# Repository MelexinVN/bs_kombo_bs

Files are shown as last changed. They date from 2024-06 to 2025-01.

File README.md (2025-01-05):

# БС ("Брейн система")

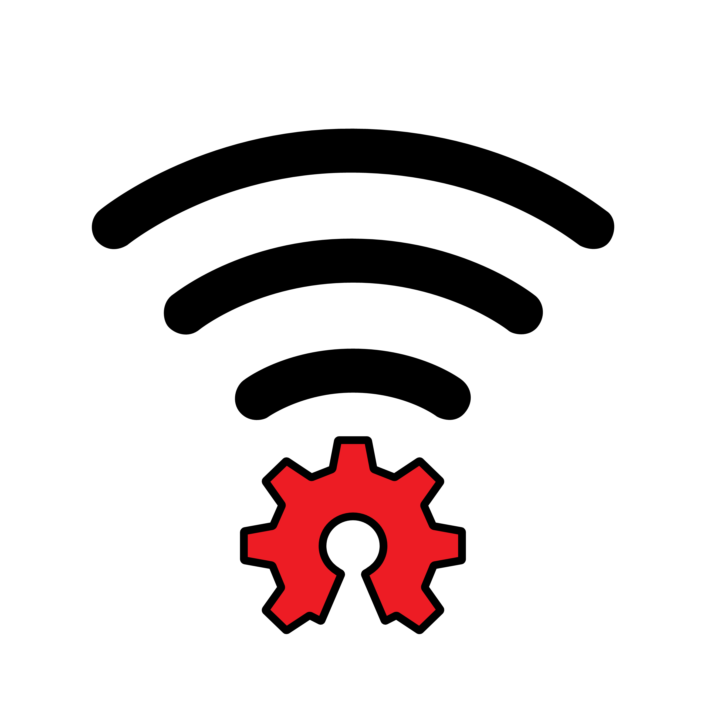
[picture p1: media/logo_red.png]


В рамках проекта ["КомБО"](https://github.com/MelexinVN/bs_kombo) разработана электронная система для проведения интеллектуальных игр.
Система без использования проводной связи позволяет устанавливать точную последовательность нажатий до 20 игровых кнопок.

As part of the project ["КомБО"](https://github.com/MelexinVN/bs_kombo), an electronic system for conducting intellectual games has been developed.
The wireless system allows you to set the exact sequence of pressing up to 20 game buttons.

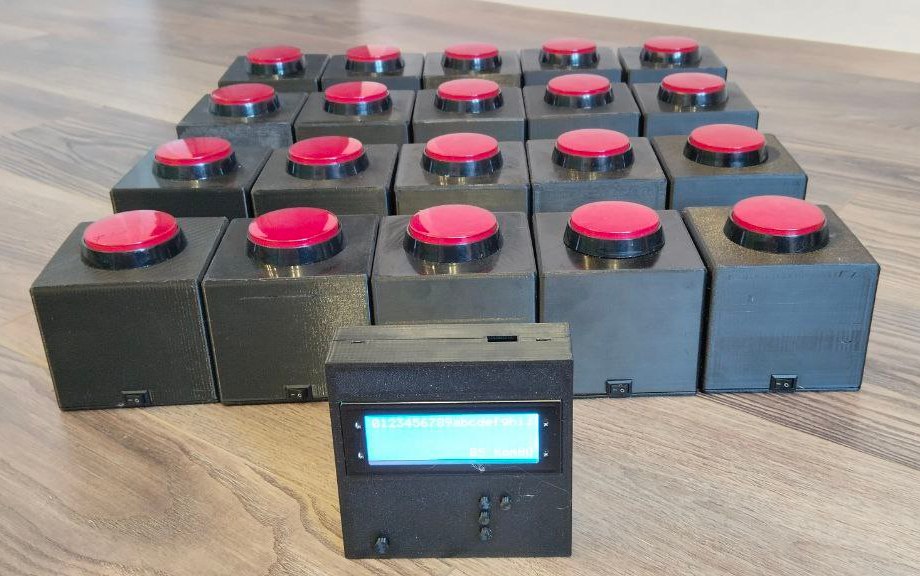
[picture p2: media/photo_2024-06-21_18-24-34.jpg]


### Основные характеристики системы

- беспроводная связь базы с игровыми кнопками
- частота радиоканала - 2,4-2,56 ГГц
- дальность связи - 30 м в помещении (может зависеть от зашумленности помещения радиосигналами, перегородок и преград)
- количество кнопок - до 20 шт
- питание каждой игровой кнопки осуществляется от аккумулятора
- питание базы может осуществляться через USB кабель, а также автономно - от аккумулятора

### Main characteristics of the system

- wireless connection of the base with game buttons
- radio channel frequency - 2.4-2.56 GHz
- communication range - 30 m indoors (may depend on the noise level of the room due to radio signals, partitions and obstacles)
- number of buttons - up to 20 pcs.
- each game button is powered by a battery
- the base can be powered via a USB cable, or autonomously - from a battery

### Основные функции системы

- отображение хода игры на дисплее и в специальной программе на ПК
- воспроизведение звуковых файлов (mp3) при различных событиях как через ПК, так и автономно
- возможность замены звуковых файлов
- отдельная индикация первой нажатой игровой кнопки
- возможность перехода очереди нажатых кнопок
- возможность запуска времени и фиксации фальстарта

### Basic system functions

- display of the game progress on the display and in a special program on the PC
- playback of sound files (mp3) for various events both via a PC and autonomously
- ability to replace sound files
- separate indication of the first pressed game button
- the ability to move through the queue of pressed buttons
- ability to start time and fix false start

### Состав системы System composition

Система состоит из базы и комплекта игровых кнопок.

The system consists of a base and a set of game buttons.

База содержит контроллер (stm32f103c8t6 на плате bluepill), дисплей LCD2004, радиомодуль nrf24l01+, кнопки управления, USB-мост CP2102, звуковой модуль DFPlayer mini и схему питания.

The base contains a controller (stm32f103c8t6 on a bluepill board), an LCD2004 display, an nrf24l01+ radio module, control buttons, a CP2102 USB bridge, a DFPlayer mini sound module and a power circuit.

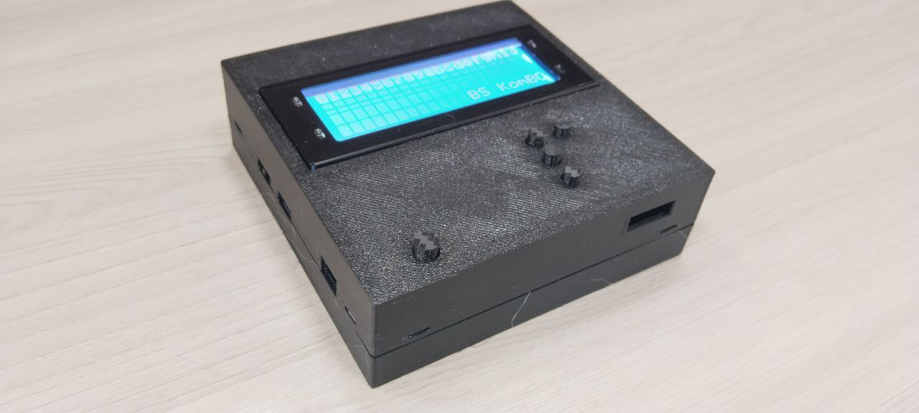
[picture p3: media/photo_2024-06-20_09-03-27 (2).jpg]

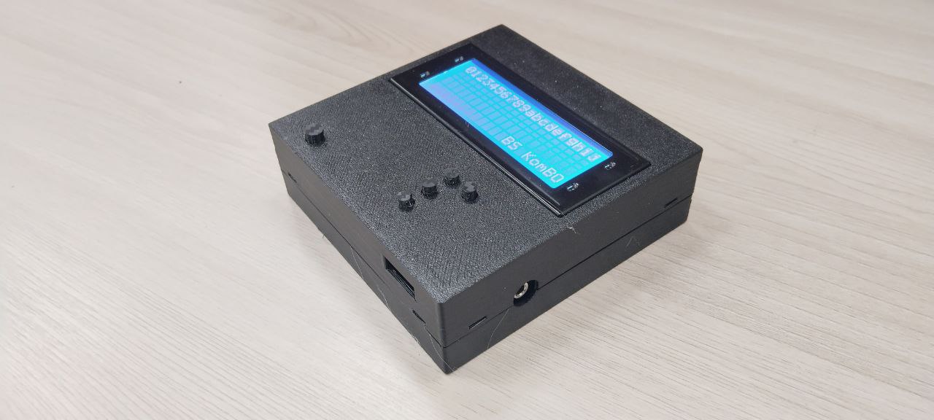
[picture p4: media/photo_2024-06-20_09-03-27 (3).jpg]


Каждая игровая кнопка содержит схему управления на микроконтроллере stm32f030f4p6 с радиомодулем nrf24l01+, схему питания и аркадную кнопку.

Each game button contains a control circuit on a stm32f030f4p6 microcontroller with an nrf24l01+ radio module, a power circuit and an arcade button.

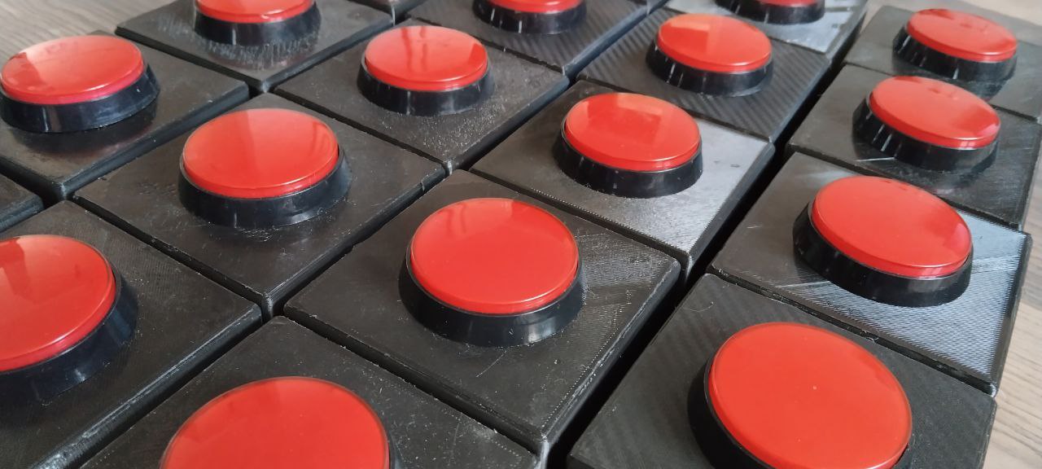
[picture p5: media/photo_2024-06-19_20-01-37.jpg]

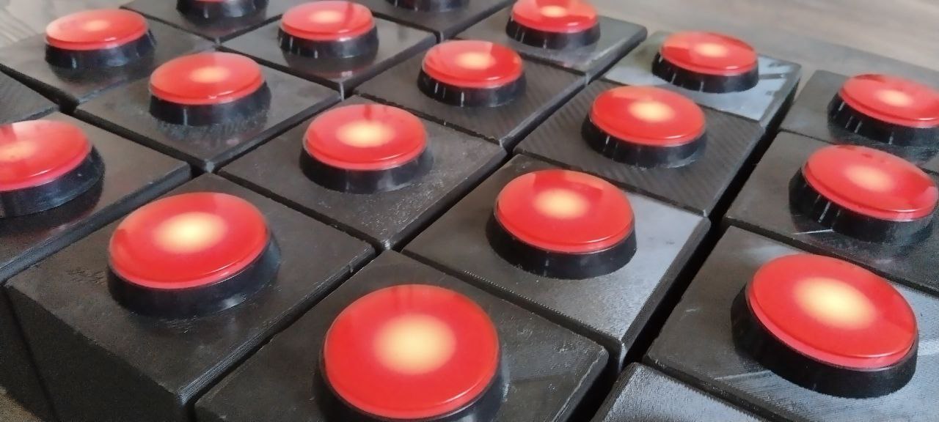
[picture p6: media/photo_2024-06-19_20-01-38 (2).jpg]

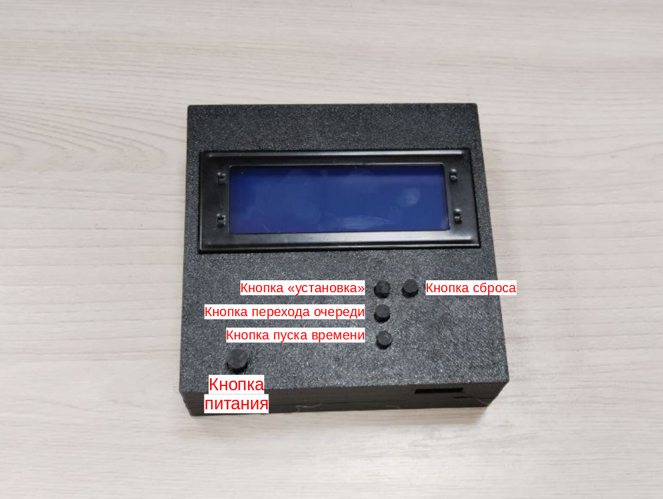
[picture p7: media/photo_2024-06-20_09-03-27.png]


### Схема соединений игровой кнопки Game Button Connection Diagram

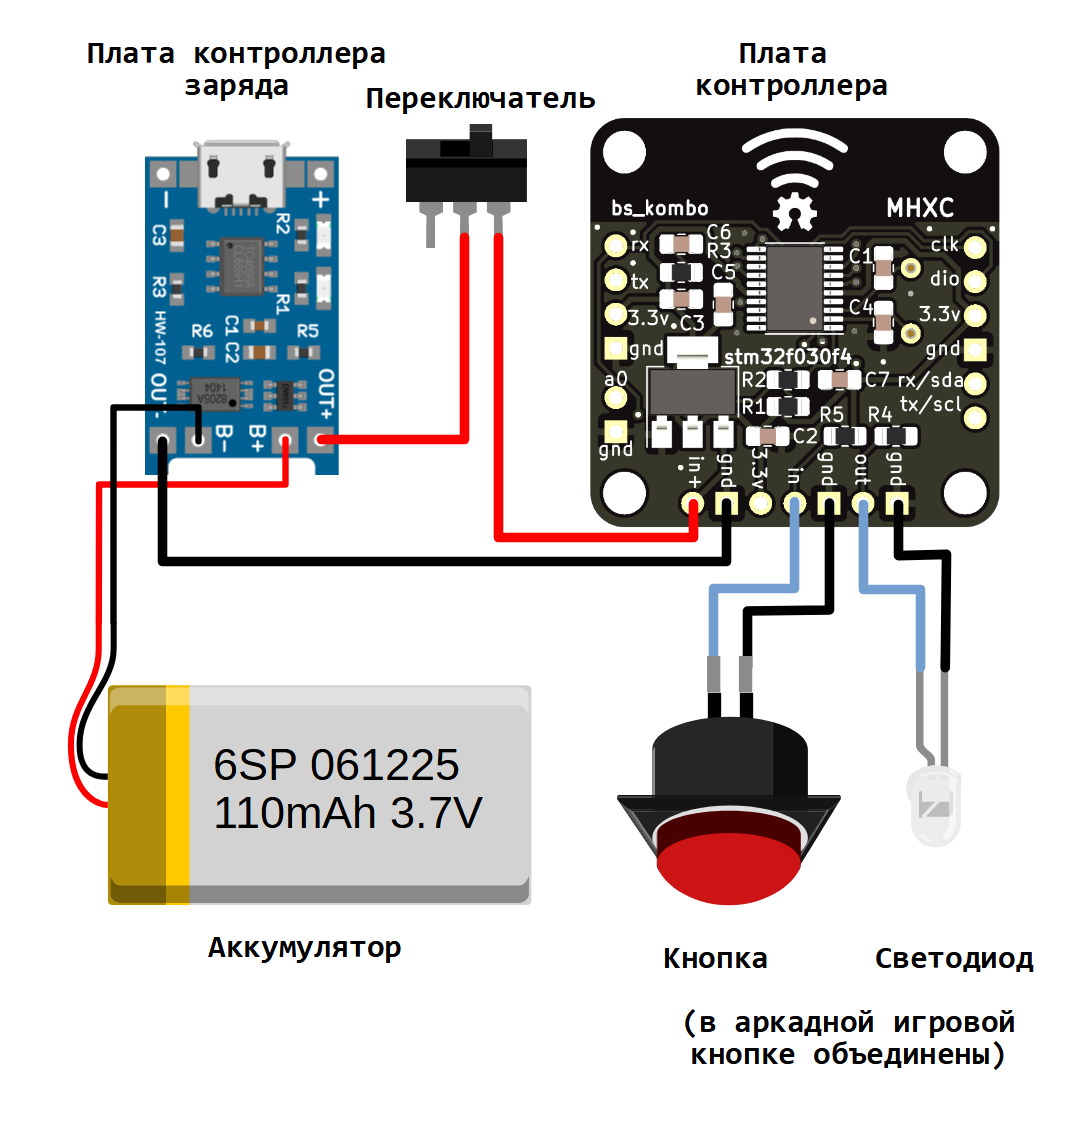
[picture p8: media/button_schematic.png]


### Программное обеспечение

- МикроПО базы и игровой кнопки написаны в Keil uVision, есть вариант в STM32CubeIDE.
- ПО для ОС Windows написано в Visual Studio.

Все [исходники](https://github.com/MelexinVN/bs_kombo_bs/blob/main/soft) доступны в репозитории.

Готовые файлы прошивок доступны по следующим ссылкам - [прошивка базы](https://disk.yandex.ru/d/3vqxKnFV9-CHBA), [прошивки игровых кнопок (20 штук)](https://disk.yandex.ru/d/9PwJGGSHZjBadQ).

### Software

- The microsoftware base and buttons are written in Keil uVision, there is an option in STM32CubeIDE.
- Software for Windows OS is written in Visual Studio.

All [sources](https://github.com/MelexinVN/bs_kombo_bs/blob/main/soft) are available in the repository.

Ready-made firmware files are available at the following links - [base firmware](https://disk.yandex.ru/d/3vqxKnFV9-CHBA), [gaming button firmware (20 pieces)](https://disk.yandex.ru/d/9PwJGGSHZjBadQ).

### Печатные платы

Печатные платы разработаны в KiCad 7.0, [исходники и гребер файлы](https://github.com/MelexinVN/bs_kombo_bs/blob/main/pcb) также есть в репозитории - [плата контроллера кнопки](https://github.com/MelexinVN/bs_kombo_bs/blob/main/pcb/bs_button_v.1.0), [плата базы](https://github.com/MelexinVN/bs_kombo_bs/blob/main/pcb/bs_base_v.1.0)

### Printed circuit boards

The printed circuit boards were developed in KiCad 7.0, [source and comb files](https://github.com/MelexinVN/bs_kombo_bs/blob/main/pcb) also available in the repository - [button controller board](https://github.com/MelexinVN/bs_kombo_bs/blob/main/pcb/bs_button_v.1.0), [base board](https://github.com/MelexinVN/bs_kombo_bs/blob/main/pcb/bs_base_v.1.0)

### Корпуса

Корпуса и вспомогательные детали изготовлены при помощи 3Д печати.
Модели корпусов разработаны в программе OpenSCAD, [исходники и STL файлы](https://github.com/MelexinVN/bs_kombo_bs/blob/main/3d) доступны в репозитории - [корпус кнопки](https://github.com/MelexinVN/bs_kombo_bs/blob/main/3d/button_box_v.1.0), [корпус и детали базы](https://github.com/MelexinVN/bs_kombo_bs/blob/main/3d/base_box_v.1.0)

### Housings

The housings and auxiliary parts are made using 3D printing.
Case models were developed in the OpenSCAD program, [sources and STL files](https://github.com/MelexinVN/bs_kombo_bs/blob/main/3d) are available in the repository - [button case](https://github.com/MelexinVN/bs_kombo_bs/blob/main/3d/button_box_v.1.0), [body and base details](https://github.com/MelexinVN/bs_kombo_bs/blob/main/3d/base_box_v.1.0)

### Краткое описание работы системы

После включения питания каждой игровой кнопки, ее светодиод производит три коротких моргания (при неисправности радиомодуля - одно). После чего игровая кнопка готова к работе
*Примечание: таким образом можно оценить состояние питания игровой кнопки - при низкой яркости аккумулятор разряжен, при отсутствии морганий возможна неисправность схемы питания*

После включения питания базы на дисплей выводится информация о устройстве, версии ПО, состоянию радиомодуля, номере канала.
Через секунду база отправляет в эфир команду общего сброса. База готова к работе.

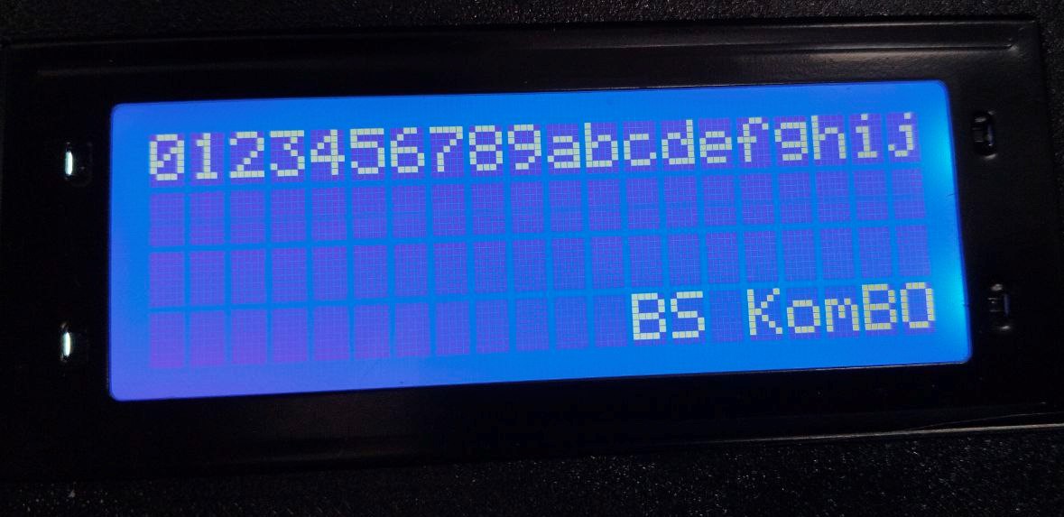
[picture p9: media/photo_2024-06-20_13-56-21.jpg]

На верхней строчке дисплея номера кнопок от "0" до "j"

По нажатию кнопки сброса система возвращается в исходное состояние и также отправляет в эфир команду общего сброса.
**Рекомендуется нажимать кнопку сброса после включения всех кнопок. Если какая то из кнопок была включена после сброса системы, возможна ошибка установления последовательности нажатий!**
Каждая игровая кнопка получившая команду сброса моргает светодиодом один раз.

После того как вся система приведена в готовность, нажатие каждой кнопки будет составлять очередь на второй строке дисплея - также от "0" до "j" и будет вопроизводиться звуковой файл. Светодиод первой нажатой игровой кнопки будет моргать, остальные - светиться.

После нажатия кнопки перехода очереди светодиод первой в очереди игровой кнопки гаснет, моргать начинает следующая в очереди.

Нажатие кнопки пуска времени приводит к началу отсчета времени - воспроизводится соответствующий звуковой сигнал, а на дисплее появляется таймер, отсчитывающий секунды. 

Нажатие кнопки установки приводит к изменению звукового файла, воспроизводимого при нажатии игровой кнопки **ДО** пуска времени. При этом на дисплее появится название звука, один из пяти вариантов.
*Примечание: выбранный звук сохранится после нажатия кнопки сброса, но вернется к стандартному при отключении питания*

Источником звуков при автономной работе является звуковой модуль, аудиовыход которого выведен на корпус в виде аудио гнезда 3,5 мм. Звуковой модуль воспроизводит звуковые файлы формата mp3, записанные на карте памяти microSD. Файлы можно заменить, но они должны иметь те же имена. Стандартное содержимое карты памяти можно найти [тут](https://disk.yandex.ru/d/iv4f7-gtp3TiZA). Файлы должны находиться в корне карты памяти.

**Предусмотрена возможность отображения хода игры и управления системой с помощью программы верхнего уровня. Описание программы и инструкцию можно найти [тут](https://github.com/MelexinVN/bs_kombo_bs/tree/main/soft/Visual%20Studio)**

### Brief description of the system operation

After turning on the power of each game button, its LED produces three short blinks (if the radio module is faulty - one). After which the game button is ready for use
*Note: this way you can evaluate the power status of the game button - if the brightness is low, the battery is discharged, if there is no blinking, the power circuit may be faulty*

After turning on the power of the base, information about the device, software version, radio module status, and channel number is displayed.
A second later, the base sends a general reset command over the air. The base is ready for use.


On the top line of the display there are button numbers from “0” to “j”

When the reset button is pressed, the system returns to its original state and also sends a general reset command over the air.
**It is recommended to press the reset button after all buttons have been turned on. If any of the buttons was turned on after resetting the system, there may be an error in establishing the sequence of presses!**
Each game button that receives a reset command blinks its LED once.

Once the entire system is ready, pressing each button will line up on the second line of the display - also from "0" to "j" - and a sound file will be played. The LED of the first pressed game button will blink, the others will light up.

After pressing the queue switch button, the LED of the first game button in the queue goes out, and the next one in the queue starts blinking.

Pressing the start time button starts the countdown - a corresponding sound signal is played, and a timer appears on the display, counting down the seconds.

Pressing the set button changes the sound file played when the game button **BEFORE** the time starts is pressed. In this case, the name of the sound will appear on the display, one of five options.
*Note: The selected sound will remain after pressing the reset button, but will return to standard when the power is turned off*

The source of sounds during autonomous operation is the sound module, the audio output of which is connected to the case in the form of a 3.5 mm audio jack. The sound module plays mp3 audio files recorded on a microSD memory card. The files can be replaced, but they must have the same names. The standard contents of the memory card can be found [here](https://disk.yandex.ru/d/iv4f7-gtp3TiZA). The files must be located in the root of the memory card.

**It is possible to display the progress of the game and control the system using a top-level program. A description of the program and instructions can be found [here](https://github.com/MelexinVN/bs_kombo_bs/tree/main/soft/Visual%20Studio)**

### Планы по развитию:
- **Переход на более компактную базу с цветным дисплеем**
- **Отображение информации о наличии кнопок в эфире**
- **Отображение информации об уровнях заряда кнопок и базы**
- **Добавление возможности перехода на другие радиоканалы в случае зашумленности помещения**
- **Более гибкая настройка программы верхнего уровня для большей информативности и для разных видов интеллектуальных игр**

### Development plans:
- **Transition to a more compact base with a color display**
- **Displaying information about the presence of buttons on air**
- **Display information about charge levels of buttons and base**
- **Adding the ability to switch to other radio channels in case of a noisy room**
- **More flexible configuration of the top-level program for greater information content and for different types of intellectual games**

## Наши ресурсы:

### Основной репозиторий: [bs_kombo](https://github.com/MelexinVN/bs_kombo)

### Электронная почта: 		    [bskombo@yandex.ru](bskombo@yandex.ru)

### Социальные сети:

- паблик ВКонтакте: 			  [vk.com/bs_kombo](https://vk.com/bs_kombo)
- Telegram-канал: 	        [t.me/bskombo](https://t.me/bskombo)
- Telegram-чат: 	          [t.me/bs_kombo_chat](https://t.me/bs_kombo_chat)

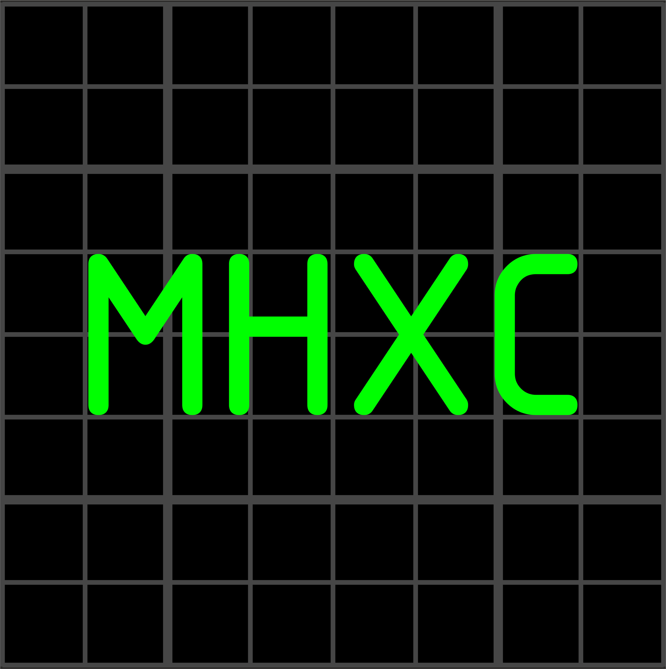
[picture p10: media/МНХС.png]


### Авторы всегда рады отзывам и любым конструктивным предложениям по улучшению проекта! 
### The authors are always happy to receive feedback and any constructive suggestions for improving the project!

## Лицензия
Проект распространяется под лицензией Creative Commons Attribution-ShareAlike 4.0 [CC BY-SA 4.0](https://creativecommons.org/licenses/by-sa/4.0/), 
а программное обеспечение - под лицензией GNU General Public License v3.0 [GPL-3.0 license](https://github.com/MelexinVN/bs_kombo/blob/main/LICENSE)

## License
This project is licensed under the Creative Commons 4.0 license with Attribution-ShareAlike [CC BY-SA 4.0](https://creativecommons.org/licenses/by-sa/4.0/), 
and the software is licensed under the GNU General Public License v3.0 [GPL-3.0 license](https://github.com/MelexinVN/bs_kombo/blob/main/LICENSE)

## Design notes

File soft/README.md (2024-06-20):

## Программное обеспечение системы.

### В папке [Keil uVision](https://github.com/MelexinVN/bs_kombo_bs/blob/main/soft/Keil%20uVision) содержатся проекты программ функционирования базы и игровых кнопок, написанные в среде Keil версии 5.38 преимущественно на языке Си

### В папке [STM32CubeIDE](https://github.com/MelexinVN/bs_kombo_bs/blob/main/soft/STM32CubeIDE) содержатся проекты программ функционирования базы и игровых кнопок, написанные в среде STM32CubeIDE v.1.15.0 преимущественно на языке Си

### В папке [Visual Studio](https://github.com/MelexinVN/bs_kombo_bs/blob/main/soft/Visual%20Studio) содержатся исходники программы верхнего уровня для ОС Windows, написанные в Visual Studio 2019 на языке C#

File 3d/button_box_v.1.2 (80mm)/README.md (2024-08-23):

## 3Д модели 3д-печатных деталей устройства.

## Корпус игровой кнопки. Версия 1.2 
- Внутренние размеры - 80x80x80 мм
- Требует меньше материала и времени на печать
- Можно печатать без поддержек и настройки "сделать нависания печатаемыми"
- Меньше радиус крепежных элементов корпуса

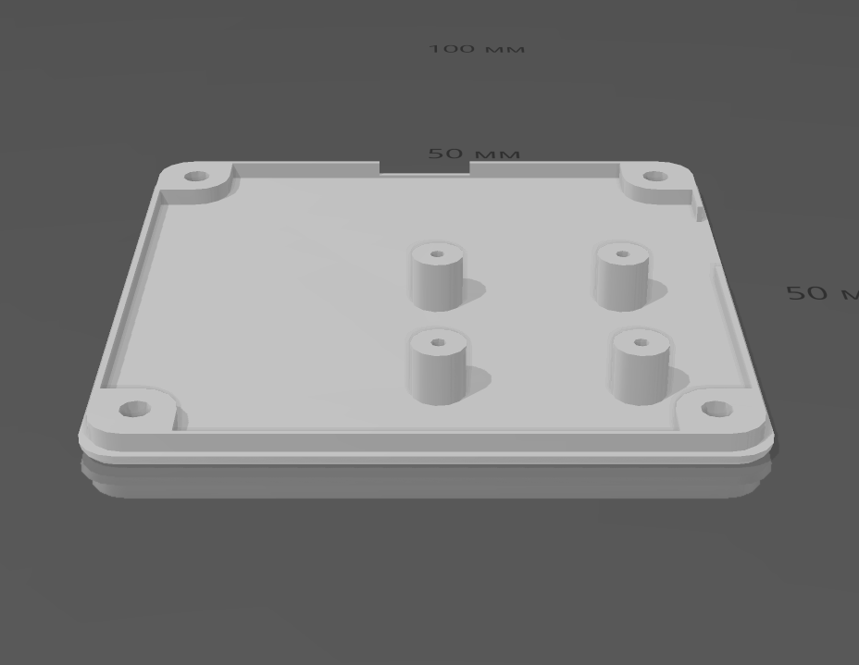
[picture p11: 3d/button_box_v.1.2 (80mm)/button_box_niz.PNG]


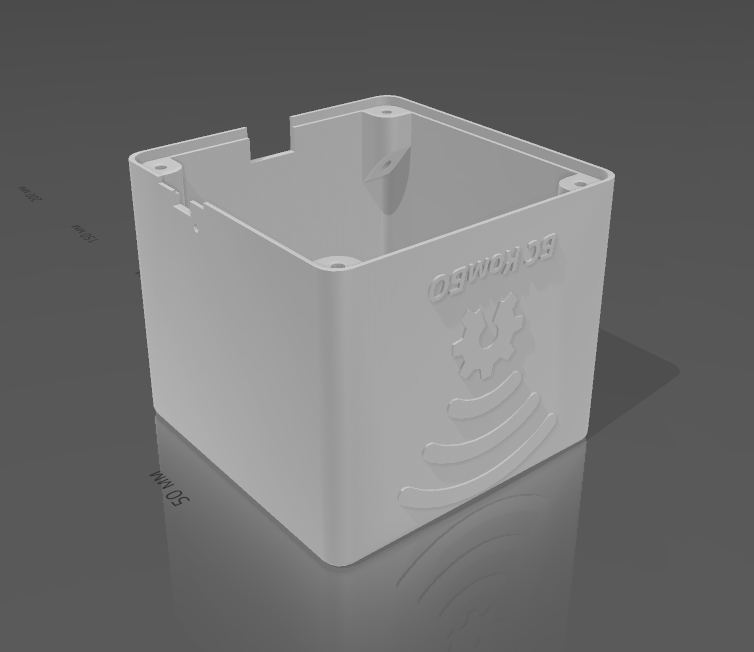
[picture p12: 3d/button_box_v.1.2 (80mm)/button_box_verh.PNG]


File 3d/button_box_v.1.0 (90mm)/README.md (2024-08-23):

## 3Д модели и исходники 3д-печатных деталей устройства.
### 3Д модели созданы в программе [OpenSCAD](https://openscad.org/)
### Корпус пульта управления создан с использованием библиотеки YAPP_Box 
### [Yet Another Parameterised Projectbox generator](https://mrwheel-docs.gitbook.io/yappgenerator_en/)
**!!! При печати нижней части корпуса кнопки без поддержек рекомендуется включить настройку "Сделать нависания печатаемыми"!!!**

## Корпус игровой кнопки
- Внутренние размеры - 90x90x90 мм

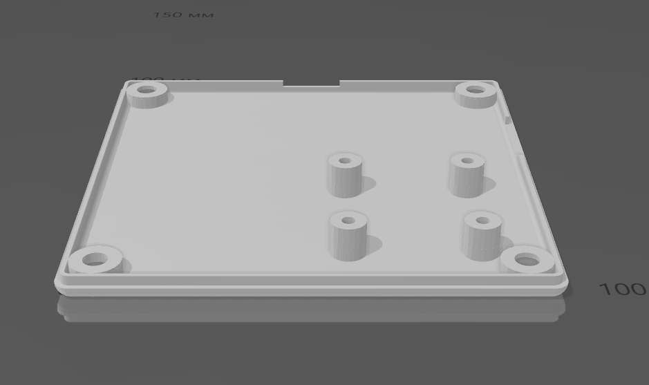
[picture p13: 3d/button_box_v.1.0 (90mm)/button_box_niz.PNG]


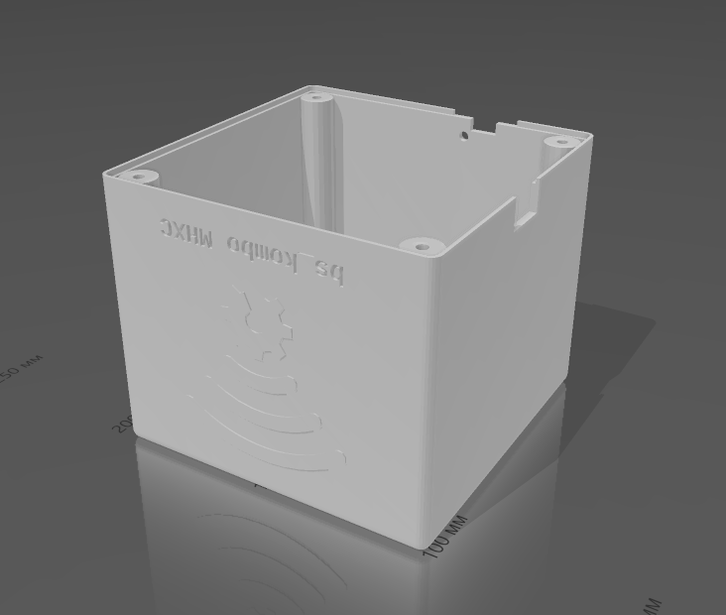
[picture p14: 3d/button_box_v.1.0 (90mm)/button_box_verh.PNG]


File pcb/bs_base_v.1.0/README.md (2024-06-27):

### Плата базы для "Брейн системы"

- интерактивный перечень элементов - [папка bom](https://github.com/MelexinVN/bs_kombo_bs/blob/main/pcb/bs_base_v.1.0/bom)
- файлы для производства - [папка production](https://github.com/MelexinVN/bs_kombo_bs/blob/main/pcb/bs_base_v.1.0/production/bs_base_2024-06-14_13-07-29)
- гербер-файлы - [bs_button.zip](https://github.com/MelexinVN/bs_kombo_bs/blob/main/pcb/bs_base_v.1.0/production/bs_base_2024-06-14_13-07-29/bs_base.zip) ([облако](https://disk.yandex.ru/d/Mso2Eh_hgUBqgA))

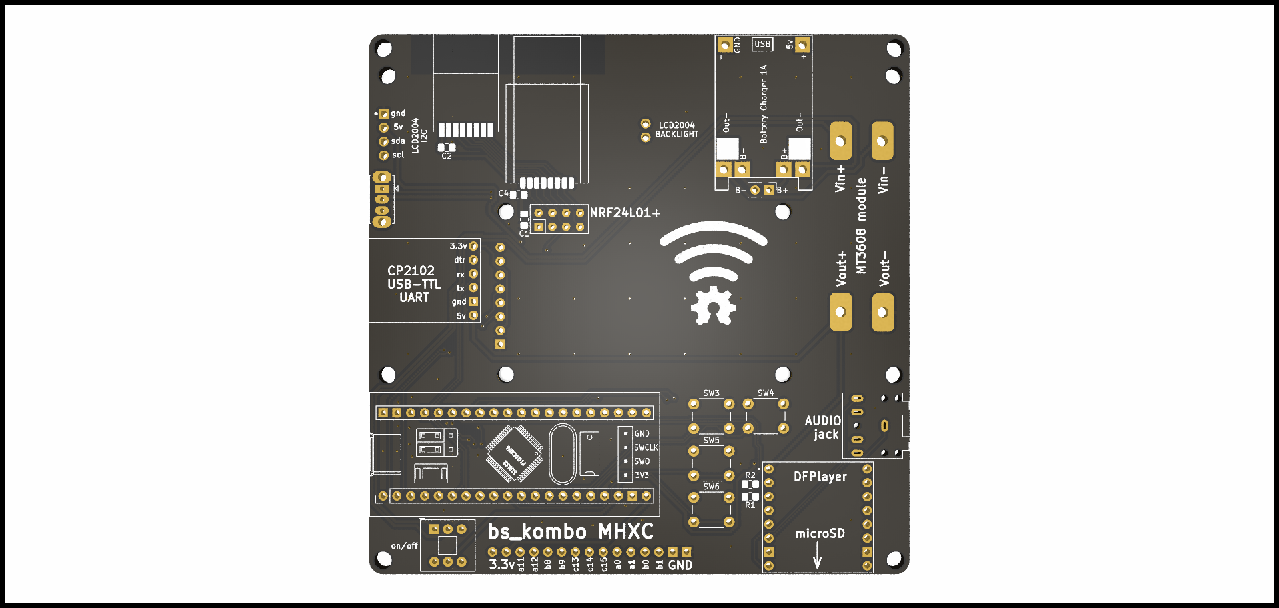
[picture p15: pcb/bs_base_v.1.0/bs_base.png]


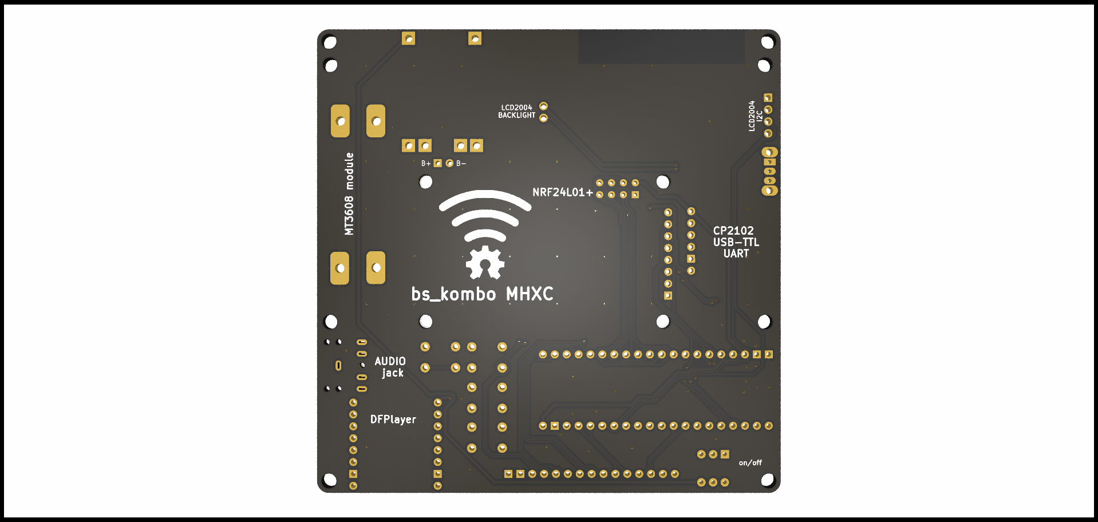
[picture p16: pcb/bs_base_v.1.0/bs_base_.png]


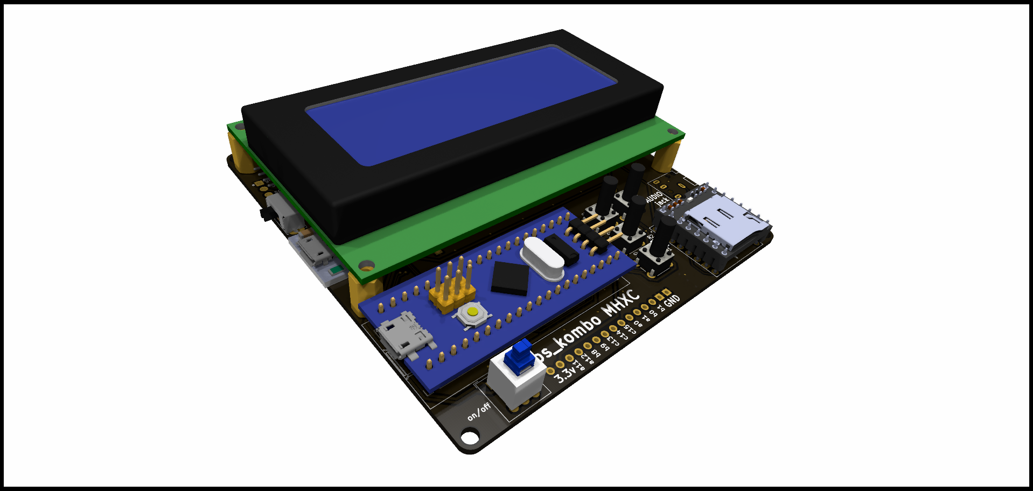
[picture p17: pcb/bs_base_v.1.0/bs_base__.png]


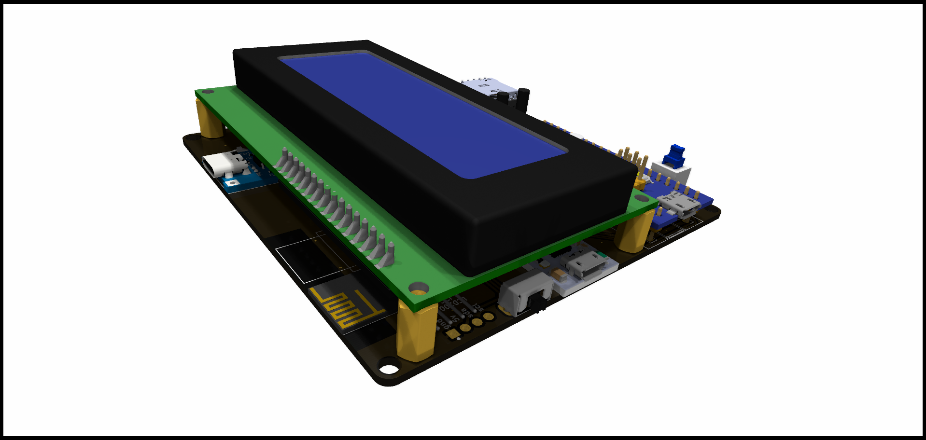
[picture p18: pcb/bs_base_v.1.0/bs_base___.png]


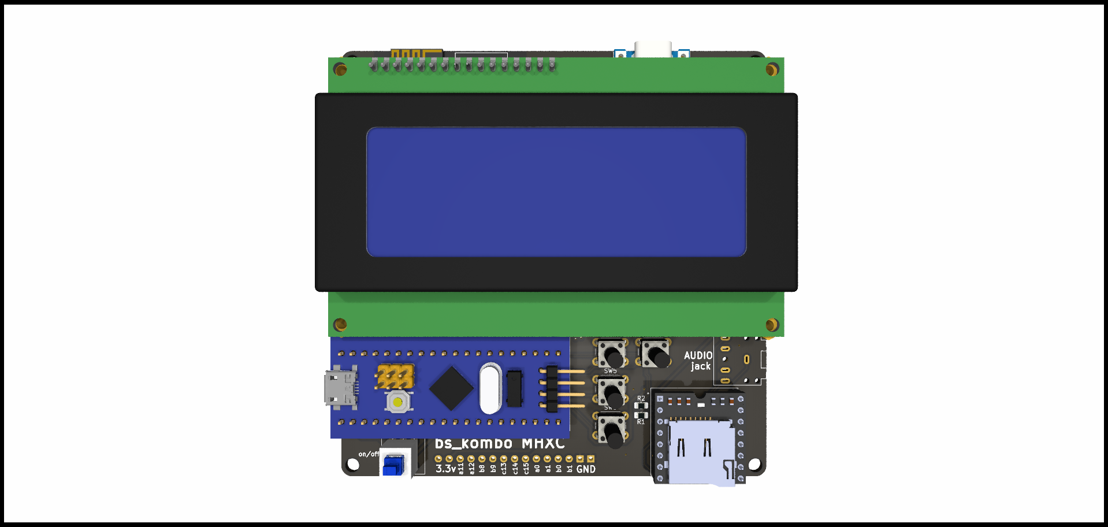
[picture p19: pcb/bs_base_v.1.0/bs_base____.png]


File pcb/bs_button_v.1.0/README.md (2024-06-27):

### Плата контроллера игровой кнопки для "Брейн системы"

- интерактивный перечень элементов - [папка bom](https://github.com/MelexinVN/bs_kombo_bs/tree/main/pcb/bs_base_v.1.0/bom)
- файлы для производства - [папка production](https://github.com/MelexinVN/bs_kombo_bs/tree/main/pcb/bs_button_v.1.0/production/bs_button_2024-06-14_13-00-54)
- гербер-файлы - [bs_button.zip](https://github.com/MelexinVN/bs_kombo_bs/tree/main/pcb/bs_button_v.1.0/production/bs_button_2024-06-14_13-00-54/bs_button.zip) ([облако](https://disk.yandex.ru/d/F6ybTHqenkIKWQ))

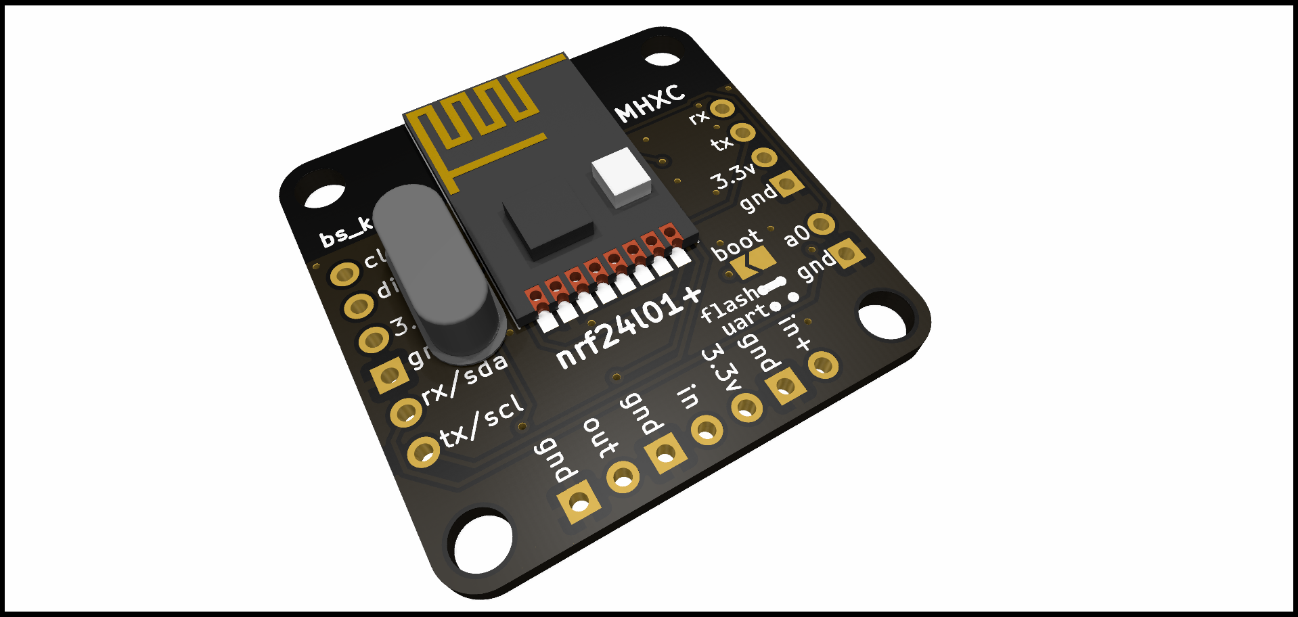
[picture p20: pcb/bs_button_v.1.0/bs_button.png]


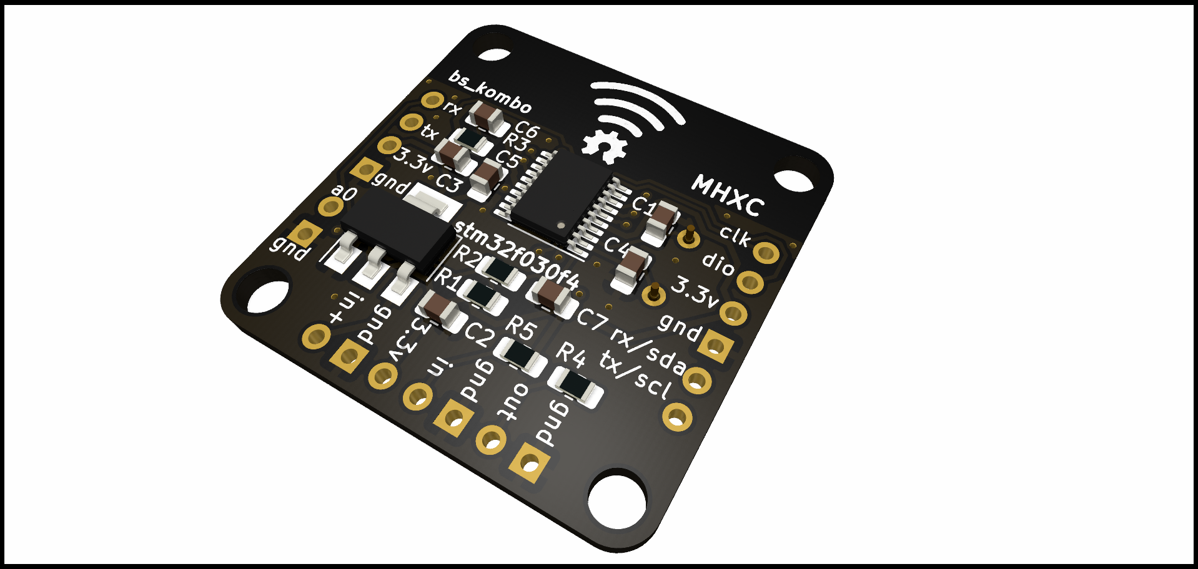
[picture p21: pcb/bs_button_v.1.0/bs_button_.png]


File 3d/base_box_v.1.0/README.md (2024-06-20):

## 3Д модели и исходники 3д-печатных деталей устройства.
### 3Д модели созданы в программе [OpenSCAD](https://openscad.org/)
### Корпус пульта управления создан с использованием библиотеки YAPP_Box 
### [Yet Another Parameterised Projectbox generator](https://mrwheel-docs.gitbook.io/yappgenerator_en/)

### Корпус базы 

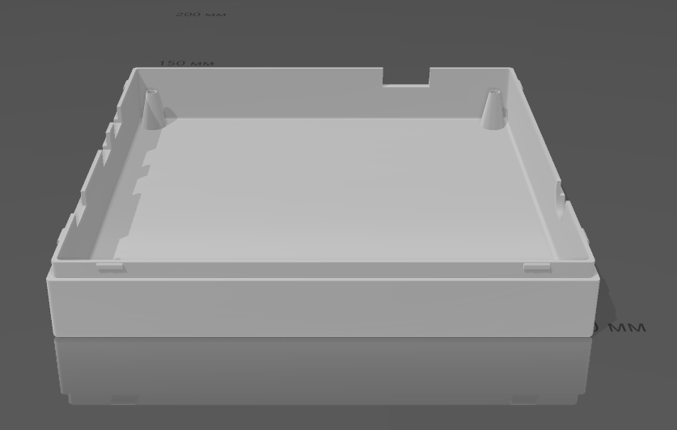
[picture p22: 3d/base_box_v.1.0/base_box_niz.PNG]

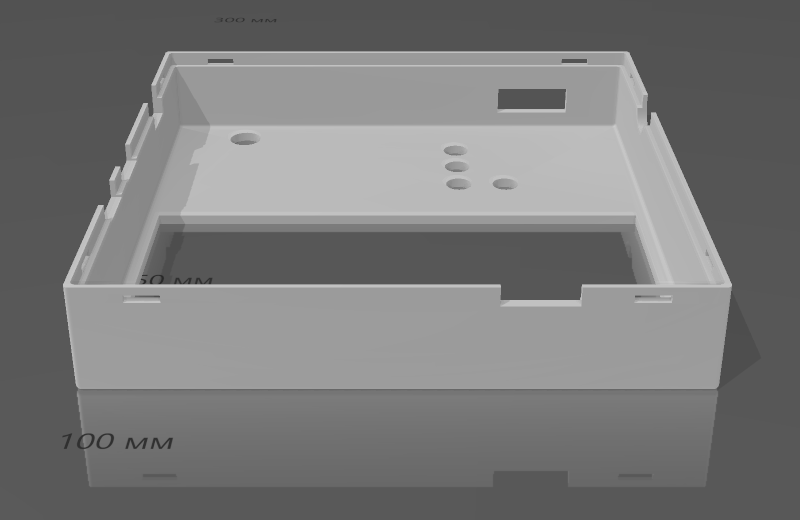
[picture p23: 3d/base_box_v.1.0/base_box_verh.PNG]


### и вспомогательные элементы:
- pcb_stand - стойки для монтажа дисплея
- button_ext_3mm, button_ext_4.5mm - насадки на кнопки

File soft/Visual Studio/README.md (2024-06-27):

##  Описание программы
Программа для отображения хода игры и управления "Брейн системой".

Программа написана для ОС Windows.

Исполняемый файл и набор звуковых файлов для воспроизведения, упакованные в ZIP архив можно скачать по [ссылке](https://disk.yandex.ru/d/Y4Qgi6eKR4TbPQ).

Для запуска программы необходимо распаковать архив и запустить файл mozgocolco.exe.
После запуска открывается **окно конфигурации** и **игровое окно**.
  
### Описание окна конфигурации

Окно конфигурации включает в себя **панель параметров порта, панель звуков, панель настроек игры, а также таблицу идентификаторов игровых кнопок**.

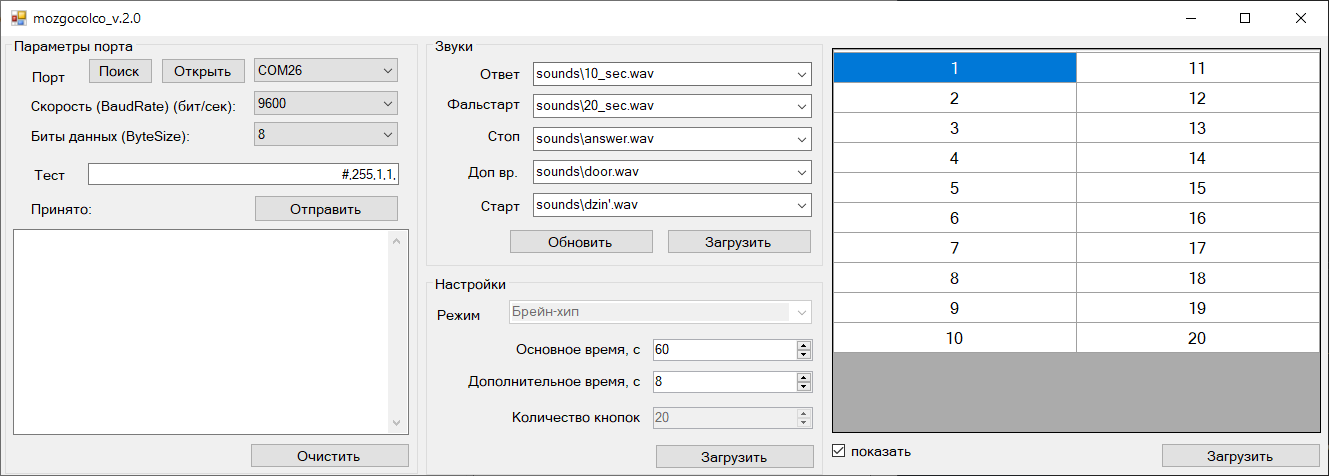
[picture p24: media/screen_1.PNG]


#### Панель параметров порта состоит из: #
- выпадающего списка выбора номера порта
- выпадающего списка скорости порта
- выпадающего списка количества битов данных
- поля для отправки тестовых данных в порт с кнопкой "отправить"
- поля вывода принятых через порт данных с кнопкой "очистить" 

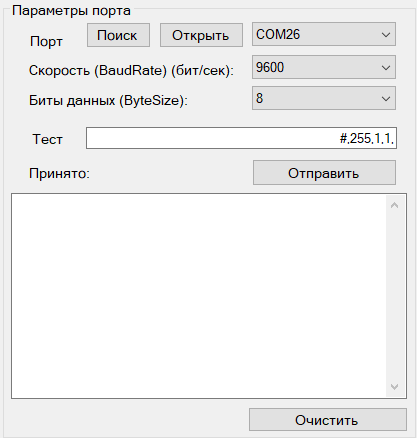
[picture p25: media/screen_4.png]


Описание работы с портом будет приведено ниже. 

*Примечание: Стандартное значение скорости порта - 9600, количества битов - 8.*

#### Панель настроек звуков состоит из: #
- выпадающих списков для выбора звуковых файлов формата mp3, воспроизводимых при соответствующих событиях
- кнопок "Обновить" и "Загрузить"

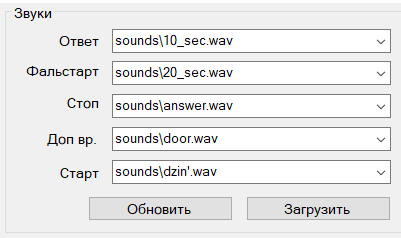
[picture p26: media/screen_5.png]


Списки формируются из содержимого папки [sounds](https://github.com/MelexinVN/bs_kombo_bs/blob/main/soft/Visual%20Studio/mozgocolco_v.2.0/bin/Debug/sounds) которая должна быть в той же папке, что и файл [mozgocolco.exe](https://github.com/MelexinVN/bs_kombo_bs/blob/main/soft/Visual%20Studio/mozgocolco_v.2.0/bin/Debug/mozgocolco.exe).

Чтобы добавить или заменить файлы в списках, нужно добавить/заменить файлы в папке и нажать кнопку "Обновить". 
После переназначения звуков на события необходимо нажать кнопку "Загрузить", чтобы изменения вступили в силу в программе.

*Примечание: В данной версии программы изменения соотвествия файлов событиям после закрытия программы не сохраняются!*

#### Панель настроек игры состоит из: #
- поля установки основного времени
- поля установки дополнительного времени
- поля для определения количества игровых кнопок
- выпадающего списка режимов игры
- кнопки "Загрузить"

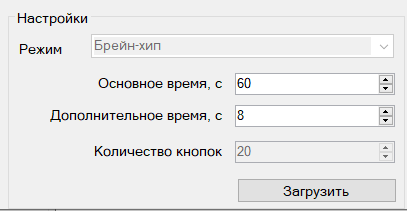
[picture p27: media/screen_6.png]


Основное время - время, которое дается на раздумье игрокам/командам. По его истечению воспроизводится соответствующий звуковой файл.

**Значение по умолчанию - 60 секунд.**

Дополнительное время - время, по прошествии которого воспроизводится дополнительный звуковой сигнал. Например - при переходе права ответа в игре "Брейн ринг".

**Значение по умолчанию - 20 секунд.**

Изменения вступают в силу при нажатии кнопки "Загрузить".

*Примечание: Изменение количества игровых кнопок и режима игры в данной версии недоступны. Изменения значений времени после закрытия программы в данной версии не сохраняются!*

#### Таблица идентификаторов игровых кнопок по умолчанию содержит их номера: #

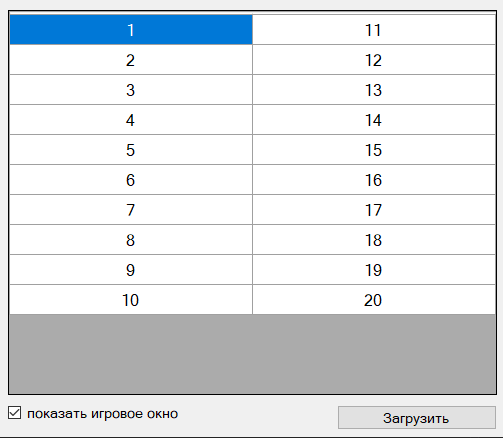
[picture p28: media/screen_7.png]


Любой идентификатор можно изменить, введя новый текст в соответствующие ячейки таблицы и нажав кнопку "Загрузить". 

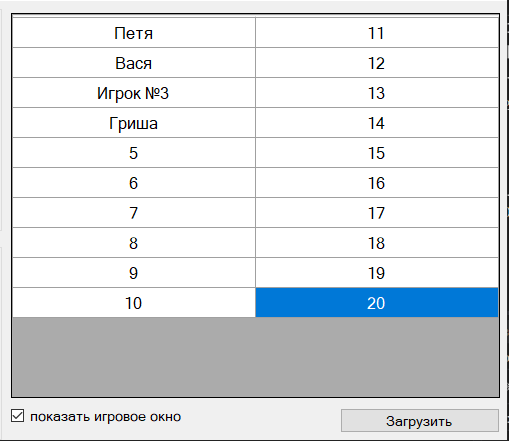
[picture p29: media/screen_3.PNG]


После изменения в поле хронологии игры в игровом окне вместо номера будет отображаться новое значение.

Под таблицей также располагается отметка "показать игровое окно", изменение которой меняет видимость игрового окна.

### Описание игрового окна

Игровое окно содержит:
- панель игровых кнопок
- панель времени
- кнопки "Сброс", "Старт" и "Далее"
- поле хронологии событий 

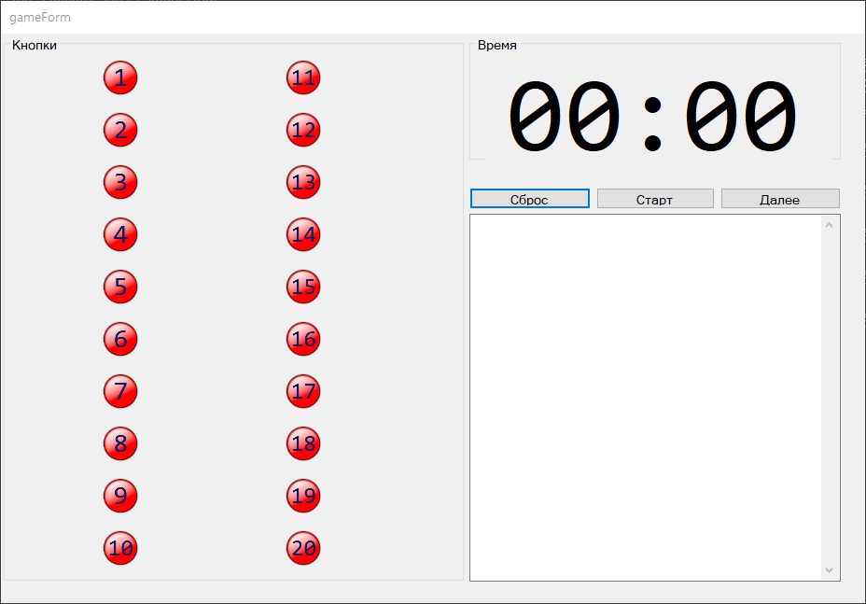
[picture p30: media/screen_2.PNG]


На панели игровых кнопок находятся пронумерованные изображения кнопок. При нажатии соответствующей игровой кнопки, справа от изображения появляется порядковый номер нажатия (начиная с нуля).  

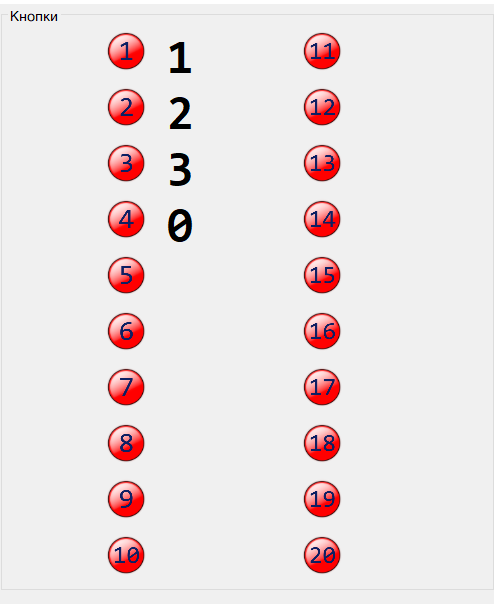
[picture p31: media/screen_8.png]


На панели времени отображается ход времени.

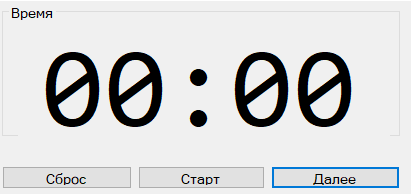
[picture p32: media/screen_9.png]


На поле хронологии событий отображается порядок нажатия игровых кнопок, а также вспомогательная информация (ФС - фальстарт). Номер игровой кнопки, название команды или имя игрока соответствуют значениям в таблице окна конфигурации.

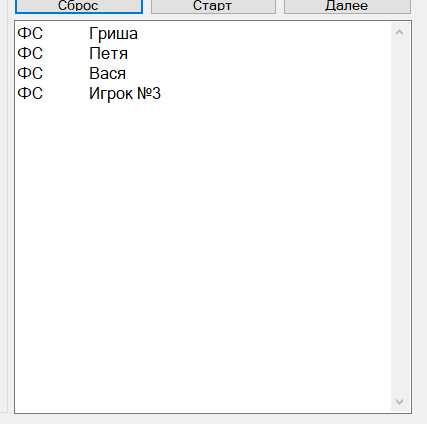
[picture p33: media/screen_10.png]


При нажатии кнопки «Сброс» система приходит в исходное состояние – исчезают номера порядка нажатия, сбрасывается таймер, очищается поле хронологии. Пульт системы и дисплей реагируют также, как и при нажатии кнопки сброса на пульте.

При нажатии кнопки «Пуск» запускается отсчет времени, система переходит в режим пуска времени.

Нажатие на кнопку «Далее» соответствует нажатию соответствующей кнопки на пульте - переход очереди нажатия. Изменение очереди также фиксируется на панели игровых кнопок.

**Горячие клавиши**

- Кнопка «Сброс» - клавиша "R" на клавиатуре
- Кнопка «Пуск» - клавиша "S" на клавиатуре
- Кнопка «Далее» - клавиша "N" на клавиатуре

## Подключение, настройка и работа с программой

Для работы программы с игровым устройством в операционной системе должны быть установлены драйвера виртуального COM-порта CP2102.

Скачать драйвер можно с [сайта производителя](https://www.silabs.com/developers/usb-to-uart-bridge-vcp-drivers?tab=downloads), или с [облака проекта](https://disk.yandex.ru/d/OVDD7t1Yv8EW7g).

*Рекомендуется подключать устройство к USB порту до запуска программы.*

После запуска программы необходимо в выпадающем списке выбора порта выбрать нужный порт и нажать кнопку "Открыть".

В случае если в выпадающем списке выбора порта отсутствует нужный порт, необходимо нажать кнопку "Поиск". 

Если после обновления порт не появится в списке, необходимо проверить исправность разъема USB, кабеля USB, корректность установки драйверов а также исправность самого устройства.

Проверить связь программы с устройством можно нажав кнопку пуска времени на устройстве (на дисплее начнется отсчет времени), а затем - кнопку сброса в игровом окне программы. Отсчет времени исчезнет.

Если после подключения порта программа не взаимодействует с устройством, необходимо проверить, тот ли порт подключен, исправен ли разъем USB, кабель USB, корректно ли установлены драйвера и исправно ли устройство.

В случае если во время работы системы произошло отключение USB разъема, необходимо переподключить устройство – подключить кабель USB к разъемуи повторить процедуру подключения.

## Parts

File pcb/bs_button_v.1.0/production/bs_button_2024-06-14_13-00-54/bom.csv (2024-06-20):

Designator | Footprint | Quantity | Value | LCSC Part #
C1, C4 | 0805 | 2 | 22p
C2, C5, C6 | 0805 | 3 | 100n
C3, C7 | 0805 | 2 | 10u
J1 | PinHeader_1x07_P2.54mm_Vertical | 1 | Conn_01x07
J2 | PinHeader_1x04_P2.54mm_Vertical | 1 | Conn_01x04
J3 | PinHeader_1x06_P2.54mm_Vertical | 1 | Conn_01x06
J4 | PinHeader_1x02_P2.54mm_Vertical | 1 | Conn_01x02
JP1 | SolderJumper-2_P1.3mm_Open_TrianglePad1.0x1.5mm | 1 | SolderJumper_2_Open
R1, R3, R5 | 0805 | 3 | 10k
R2 | 0805 | 1 | 620
R4 | 0805 | 1 | 150
U1 | NRF24L01-Module-SMD | 1 | NRF24L01_Breakout
U2 | SOT-223-3_TabPin2 | 1 | AMS1117-3.3
U3 | TSSOP-20_4.4x6.5mm_P0.65mm | 1 | STM32F030F4Px
Y1 | Crystal_HC49-U_Vertical | 1 | Crystal

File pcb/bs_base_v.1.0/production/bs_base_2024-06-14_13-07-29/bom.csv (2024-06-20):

Designator | Footprint | Quantity | Value | LCSC Part #
BT1 | PinHeader_1x02_P2.54mm_Vertical | 1 | Battery_Cell
C1, C2, C4 | 0805 | 3 | 10u
DS1 | TP4056-18650 | 1 | TP4056 module
DS2 | LCD_LCD-20X4B_i2c | 1 | LCD-20X4B
J1 | PinHeader_1x06_P2.54mm_Vertical | 1 | Conn_01x06
J2 | st7735s module | 1 | ST7735S module
J4 | Jack_3.5mm_CUI_SJ1-3525N_Horizontal | 1 | AudioJack2_Dual_Ground_Switch
J5 | PinHeader_1x15_P2.54mm_Vertical | 1 | Conn_01x15
R1, R2 | 0805 | 2 | 1K
SW1 | SW_Push_2P2T_Toggle_CK_PVA2xxH1xxxxxxV2 | 1 | SW_Push_DPDT
SW2 | SW_Slide_1P2T_CK_OS102011MS2Q | 1 | SW_SPDT
SW3, SW4, SW5, SW6 | SW_PUSH_6mm_H13mm | 4 | SW_MEC_5G
U1 | MT3608 module | 1 | MT3608 module
U2 | YAAJ_BluePill_1 | 1 | YAAJ_BluePill_Part_Like
U3 | MODULE_DFR0299 | 1 | DFR0299
U4 | NRF24L01-Module-SMD | 1 | NRF24L01_smd
U6 | nRF24L01_PA_LNA_Breakout_smd | 1 | RF_Module:nRF24L01_PA_LNA_ceramic
U7 | nRF24L01_PA_LNA_Breakout | 1 | NRF24L01_Breakout

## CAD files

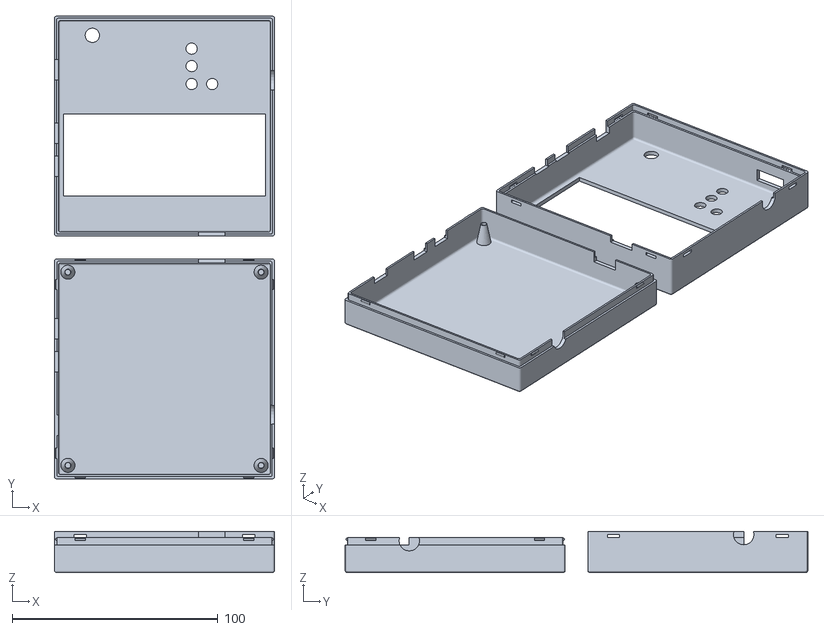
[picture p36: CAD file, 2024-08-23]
3d/base_box_v.1.0/base_box_v.1.0.stl
107.0 x 225.0 x 20.0

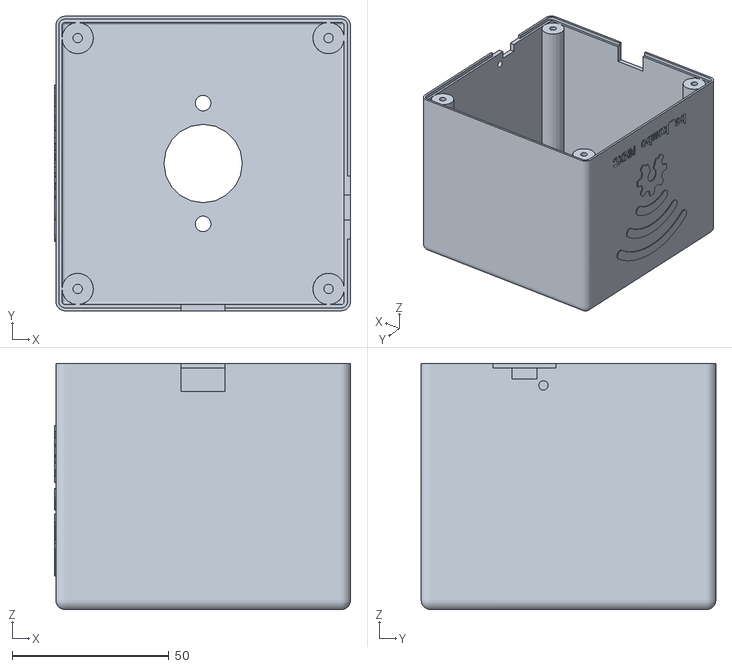
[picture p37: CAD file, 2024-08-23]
3d/button_box_v.1.0 (90mm)/button_box_verh_v.1.0.stl
94.4 x 94.0 x 78.5

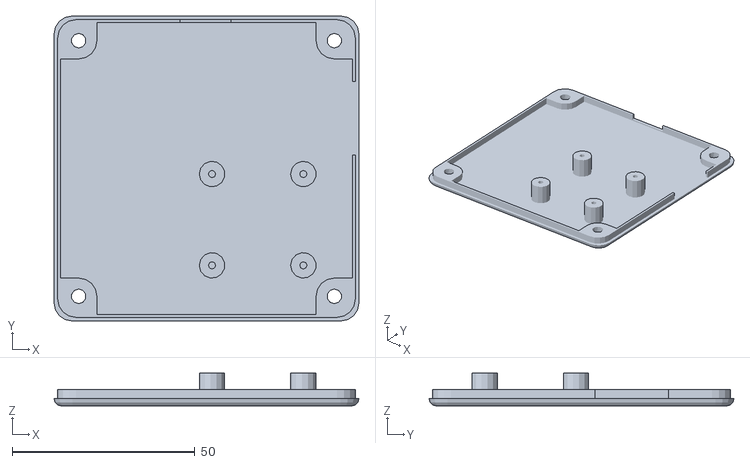
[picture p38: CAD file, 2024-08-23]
3d/button_box_v.1.2 (80mm)/box_button_v.1.2_niz.stl
83.5 x 83.5 x 9.00

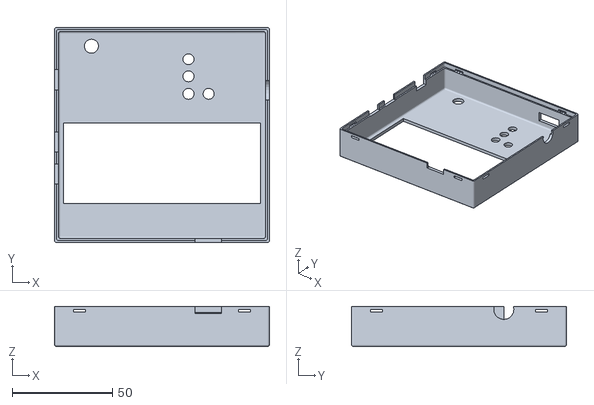
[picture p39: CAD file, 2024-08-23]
3d/base_box_v.1.0/base_box_v.1.0_verh.stl
107.0 x 107.0 x 20.0

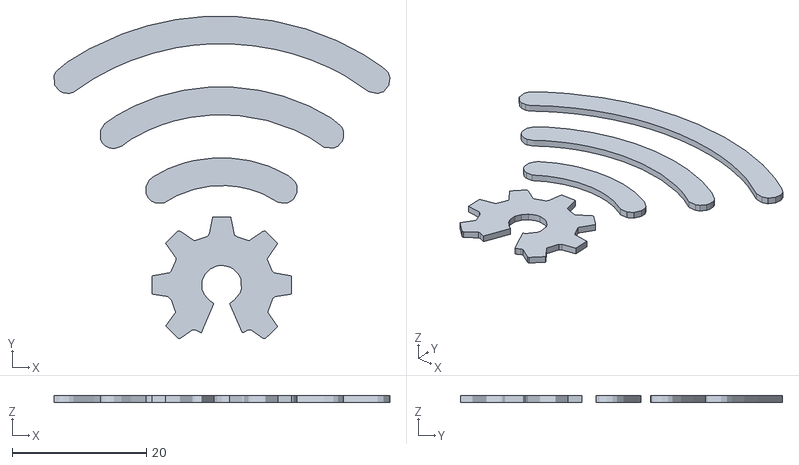
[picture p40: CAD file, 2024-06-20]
3d/button_box_v.1.0 (90mm)/logo_bs_kombo.stl
50.0 x 47.9 x 1.00

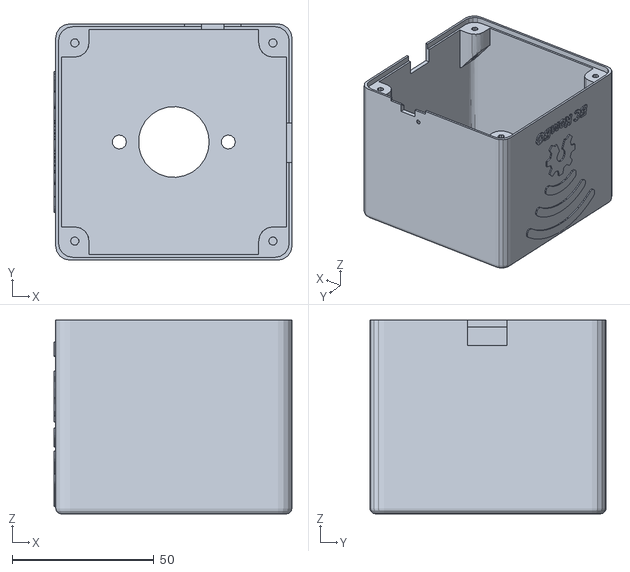
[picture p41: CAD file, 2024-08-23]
3d/button_box_v.1.2 (80mm)/box_button_v.1.2_verh.stl
84.1 x 83.5 x 68.5

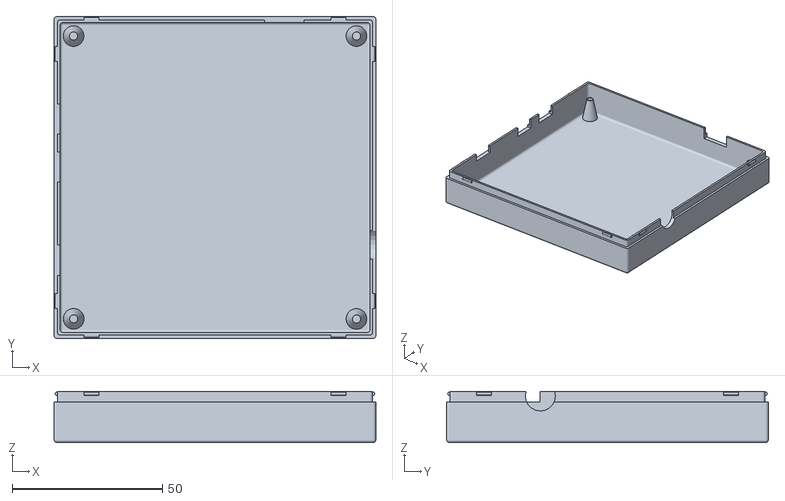
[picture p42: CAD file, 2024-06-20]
3d/base_box_v.1.0/base_box_v.1.0_niz.stl
107.0 x 107.0 x 17.0

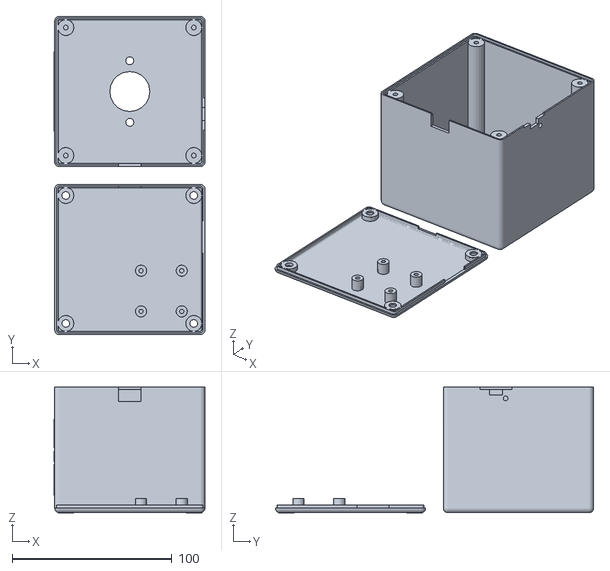
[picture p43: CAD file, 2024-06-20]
3d/button_box_v.1.0 (90mm)/button_box_v.1.0.stl
94.4 x 199.0 x 78.5

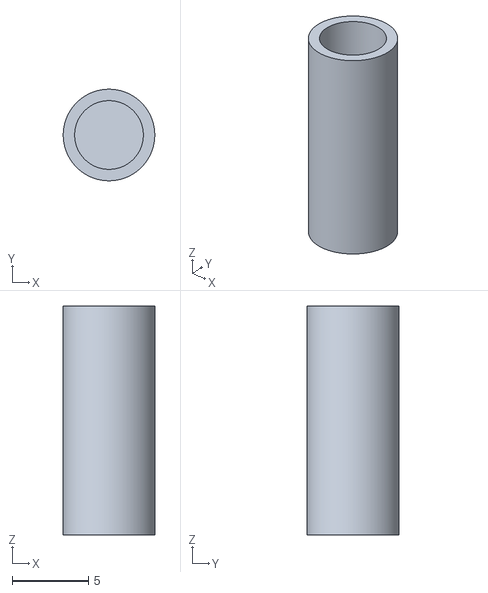
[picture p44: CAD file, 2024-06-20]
3d/base_box_v.1.0/button_ext_4.5mm.stl
6.00 x 6.00 x 15.0

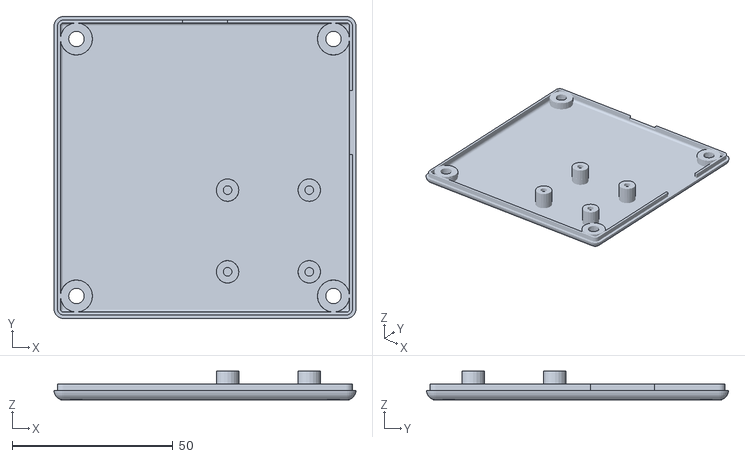
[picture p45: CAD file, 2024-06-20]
3d/button_box_v.1.0 (90mm)/button_box_niz_v.1.0.stl
94.0 x 94.0 x 9.00

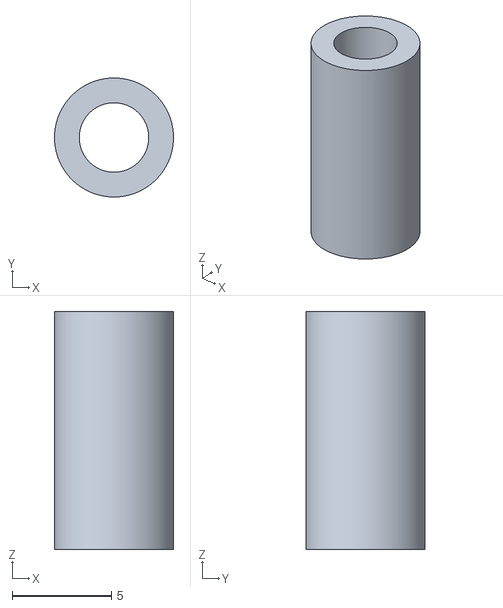
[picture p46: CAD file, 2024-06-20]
3d/base_box_v.1.0/pcb_stand.stl
6.00 x 6.00 x 12.0

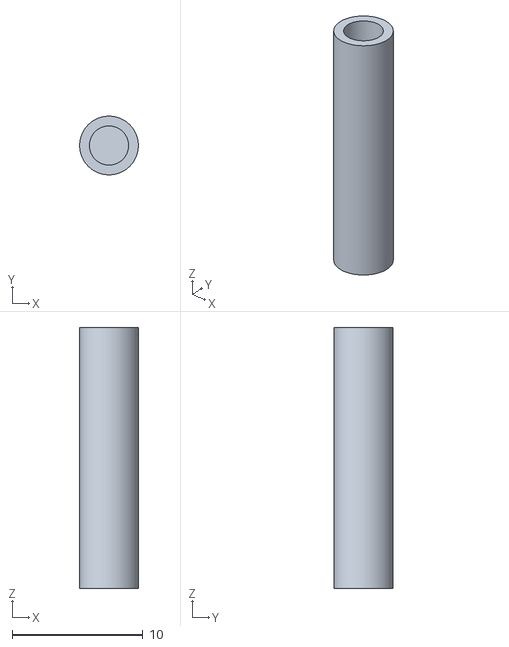
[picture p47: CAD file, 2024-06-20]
3d/base_box_v.1.0/button_ext_3mm.stl
4.50 x 4.50 x 20.0

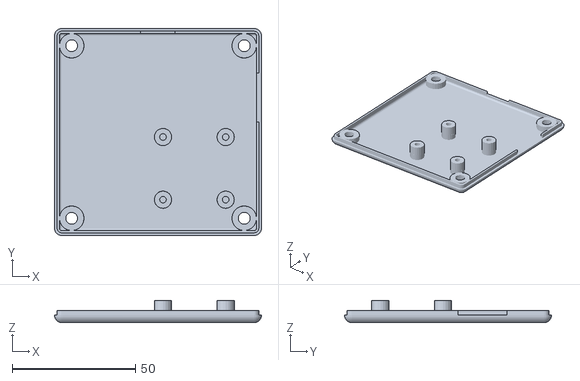
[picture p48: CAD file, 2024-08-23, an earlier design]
3d/button_box_v.1.1 (80mm)/button_box_v.1.1_niz.stl
84.0 x 84.0 x 9.00

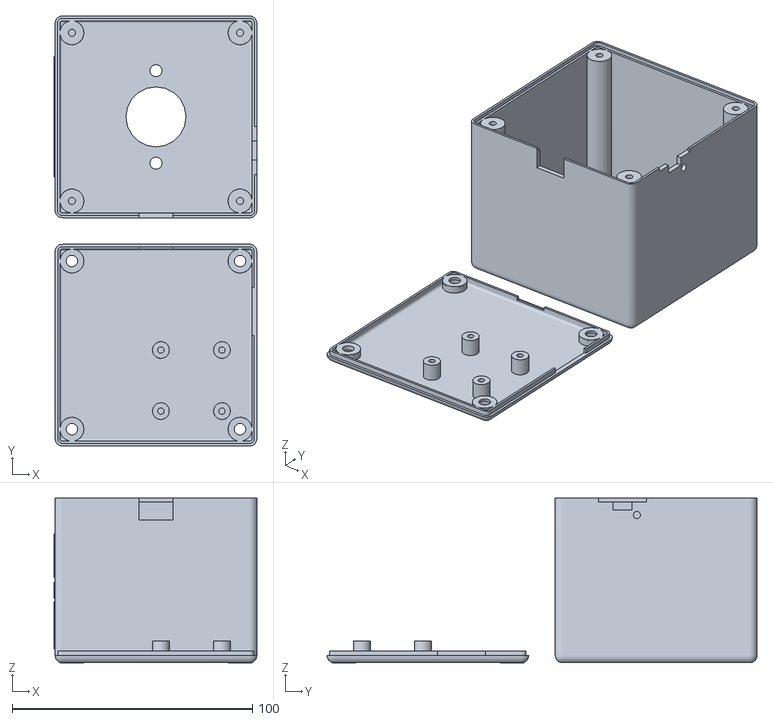
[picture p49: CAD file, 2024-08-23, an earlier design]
3d/button_box_v.1.1 (80mm)/button_box_v.1.1.stl
84.4 x 179.0 x 68.5

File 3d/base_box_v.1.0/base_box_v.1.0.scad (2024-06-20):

/***************************************************************
base_box.scad
Программа генерации 3д модели корпуса базы
Электронной системы для проведения интеллектуальных игр
("Брейн системы") проекта КомБО (Открытые системы беспроводной коммуникации)

Версия 1.0

Используется библиотека YAPP_Box 
Yet Another Parameterised Projectbox generator
https://mrwheel-docs.gitbook.io/yappgenerator_en/

Автор: MelexinVN (Мелехин В.Н.)
***************************************************************/

//---------------------------------------------------------
// This design is parameterized based on the size of a PCB.
//---------------------------------------------------------
include <library/YAPPgenerator_v16.scad>

// Note: length/lengte refers to X axis, 
//       width/breedte to Y, 
//       height/hoogte to Z

/*
      padding-back|<------pcb length --->|<padding-front
                            RIGHT
        0    X-as ---> 
        +----------------------------------------+   ---
        |                                        |    ^
        |                                        |   padding-right 
        |                                        |    v
        |    -5,y +----------------------+       |   ---              
 B    Y |         | 0,y              x,y |       |     ^              F
 A    - |         |                      |       |     |              R
 C    a |         |                      |       |     | pcb width    O
 K    s |         |                      |       |     |              N
        |         | 0,0              x,0 |       |     v              T
      ^ |   -5,0  +----------------------+       |   ---
      | |                                        |    padding-left
      0 +----------------------------------------+   ---
        0    X-as --->
                          LEFT
*/

//-- which half do you want to print?
printLidShell       = true;
printBaseShell      = true;

//-- Edit these parameters for your own board dimensions
wallThickness       = 2;//1.8;
basePlaneThickness  = 2;//1.2;
lidPlaneThickness   = 2;//1.2;

//-- Total height of box = basePlaneThickness + lidPlaneThickness 
//--                     + baseWallHeight + lidWallHeight
//-- space between pcb and lidPlane :=
//--      (baseWallHeight+lidWallHeight) - (standoffHeight+pcbThickness)
baseWallHeight      = 15;
lidWallHeight       = 15;

//-- ridge where base and lid off box can overlap
//-- Make sure this isn't less than lidWallHeight
ridgeHeight         = 3.5;
ridgeSlack          = 0.2;
roundRadius         = 1.0;

//-- pcb dimensions
pcbLength           = 99;
pcbWidth            = 99;
pcbThickness        = 1.5;

//-- How much the PCB needs to be raised from the base
//-- to leave room for solderings and whatnot
standoffHeight      = 10.0;
pinDiameter         = 2.0;
pinHoleSlack        = 0.5;
standoffDiameter    = 3;
standoffSupportHeight   = 10.0;
standoffSupportDiameter = 2.0;
                            
//-- padding between pcb and inside wall
paddingFront        = 2;
paddingBack         = 2;
paddingRight        = 2;
paddingLeft         = 2;


//-- D E B U G ----------------------------
showSideBySide      = 1;       //-> true
onLidGap            = 0;
shiftLid            = 1;
hideLidWalls        = false;       //-> false
colorLid            = "yellow";   
hideBaseWalls       = false;       //-> false
colorBase           = "white";
showPCB             = false;      //-> false
showMarkers         = false;      //-> false
inspectX            = 0;  //-> 0=none (>0 from front, <0 from back)
inspectY            = 0;
//-- D E B U G ----------------------------


//-- pcb_standoffs  -- origin is pcb[0,0,0]
// (0) = posx
// (1) = posy
// (2) = { yappBoth | yappLidOnly | yappBaseOnly }
// (3) = { yappHole, YappPin }
pcbStands = [
                 [2.54,2.54,yappBaseOnly,yappHole]
                ,[pcbLength-2.5,2.5,yappBaseOnly,yappHole]
                ,[2.5,pcbWidth-2.5,yappBaseOnly,yappHole]
                ,[pcbLength-2.5,pcbWidth-2.5,yappBaseOnly,yappHole]
             ];

//-- Lid plane    -- origin is pcb[0,0,0]
// (0) = posx
// (1) = posy
// (2) = width
// (3) = length
// (4) = angle
// (5) = { yappRectangle | yappCircle }
// (6) = { yappCenter }
cutoutsLid =  [ 
                //Отверстия под дисплей и кнопки управления
                  [0.5, 43.5, 40, 98, 0, yappRectangle]
                 ,[62.7, 11.8, 5.5, 10, 0, yappCircle,yappCenter]
                 ,[62.7, 20.3, 5.5, 10, 0, yappCircle,yappCenter]
                 ,[62.7, 29, 5.5, 10, 0, yappCircle,yappCenter]
                 ,[72.7, 29, 5.5, 10, 0, yappCircle,yappCenter]
                 ,[14.4, 5.3, 7, 10, 0, yappCircle,yappCenter]
              ];

//-- base plane    -- origin is pcb[0,0,0]
// (0) = posx
// (1) = posy
// (2) = width
// (3) = length
// (4) = angle
// (5) = { yappRectangle | yappCircle }
// (6) = { yappCenter }
cutoutsBase = [

              ];

//-- front plane  -- origin is pcb[0,0,0]
// (0) = posy
// (1) = posz
// (2) = width
// (3) = height
// (4) = angle
// (5) = { yappRectangle | yappCircle }
// (6) = { yappCenter }
cutoutsFront =  [
                    //Отверстие под аудио выход
                     [27.2, 2, 10, 2, 0, yappCircle, yappCenter]
                ];

//-- back plane  -- origin is pcb[0,0,0]
// (0) = posy
// (1) = posz
// (2) = width
// (3) = height
// (4) = angle
// (5) = { yappRectangle | yappCircle }
// (6) = { yappCenter }
cutoutsBack = [
                //Отверстия под выключатель подсветки дисплея, USB выводы
                     [48, -1, 10, 5, 0, yappRectangle]
                     ,[17, 0, 10, 7, 0, yappRectangle]
                     ,[64, -1, 10, 5, 0, yappRectangle]
              ];

//-- left plane   -- origin is pcb[0,0,0]
// (0) = posx
// (1) = posz
// (2) = width
// (3) = height
// (4) = angle
// (5) = { yappRectangle | yappCircle }
// (6) = { yappCenter }
cutoutsLeft = [
                //Отверстие под SD-карту звукового модуля
                  [73, 9, 16, 6, 0, yappRectangle]
              ];

//-- right plane   -- origin is pcb[0,0,0]
// (0) = posx
// (1) = posz
// (2) = width
// (3) = height
// (4) = angle
// (5) = { yappRectangle | yappCircle }
// (6) = { yappCenter }
cutoutsRight = [
                //Отверстие под контроллер заряда аккумулятора
                    [66, -2, 13, 6, 0, yappRectangle]
               ];

//-- connectors -- origen = box[0,0,0]
// (0) = posx
// (1) = posy
// (2) = screwDiameter
// (3) = insertDiameter
// (4) = outsideDiameter
// (5) = { yappAllCorners }
connectors   = [

               ];


//-- base mounts -- origen = box[x0,y0]
// (0) = posx | posy
// (1) = screwDiameter
// (2) = width
// (3) = height
// (4..7) = yappLeft / yappRight / yappFront / yappBack (one or more)
// (5) = { yappCenter }
baseMounts   = [

               ];

               
//-- snapJons -- origen = shell[x0,y0]
// (0) = posx | posy
// (1) = width
// (2..5) = yappLeft / yappRight / yappFront / yappBack (one or more)
// (n) = { yappSymmetric }
snapJoins   =   [
                    [10,  5, yappLeft, yappRight, yappSymmetric]
                   ,[10,  5, yappFront, yappBack, yappSymmetric]
                ];

 
//-- origin of labels is box [0,0,0]
// (0) = posx
// (1) = posy/z
// (2) = orientation
// (3) = depth
// (4) = plane {lid | base | left | right | front | back }
// (5) = font
// (6) = size
// (7) = "label text"
labelsPlane =  [

                ];

module lidHook()
{
  %translate([-20, -20, 0]) cube(5);
}

//--- this is where the magic hapens ---
YAPPgenerate();

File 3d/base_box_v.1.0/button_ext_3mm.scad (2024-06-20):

$fn = 200;//количество полигонов

height = 20;
ext_diameter = 4.5;
int_diameter = 3;


    difference()
    {
        cylinder(h = height, d = ext_diameter);
        translate([0,0,2])
            cylinder(h = height, d = int_diameter);
    }
    
        

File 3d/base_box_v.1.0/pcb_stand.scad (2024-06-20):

$fn = 200;//количество полигонов

height = 12;
ext_diameter = 6;
int_diameter = 3.5;


difference()
{
    cylinder(h = height, d = ext_diameter, center = true);
    cylinder(h = height+1, d = int_diameter, center = true);
}

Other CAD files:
3d/button_box_v.1.1 (80mm)/button_box_v.1.1_verh.stl
3d/base_box_v.1.0/button_ext_4.5mm.scad
3d/button_box_v.1.0 (90mm)/button_box_v.1.0.scad
3d/button_box_v.1.1 (80mm)/button_box_v.1.1.scad

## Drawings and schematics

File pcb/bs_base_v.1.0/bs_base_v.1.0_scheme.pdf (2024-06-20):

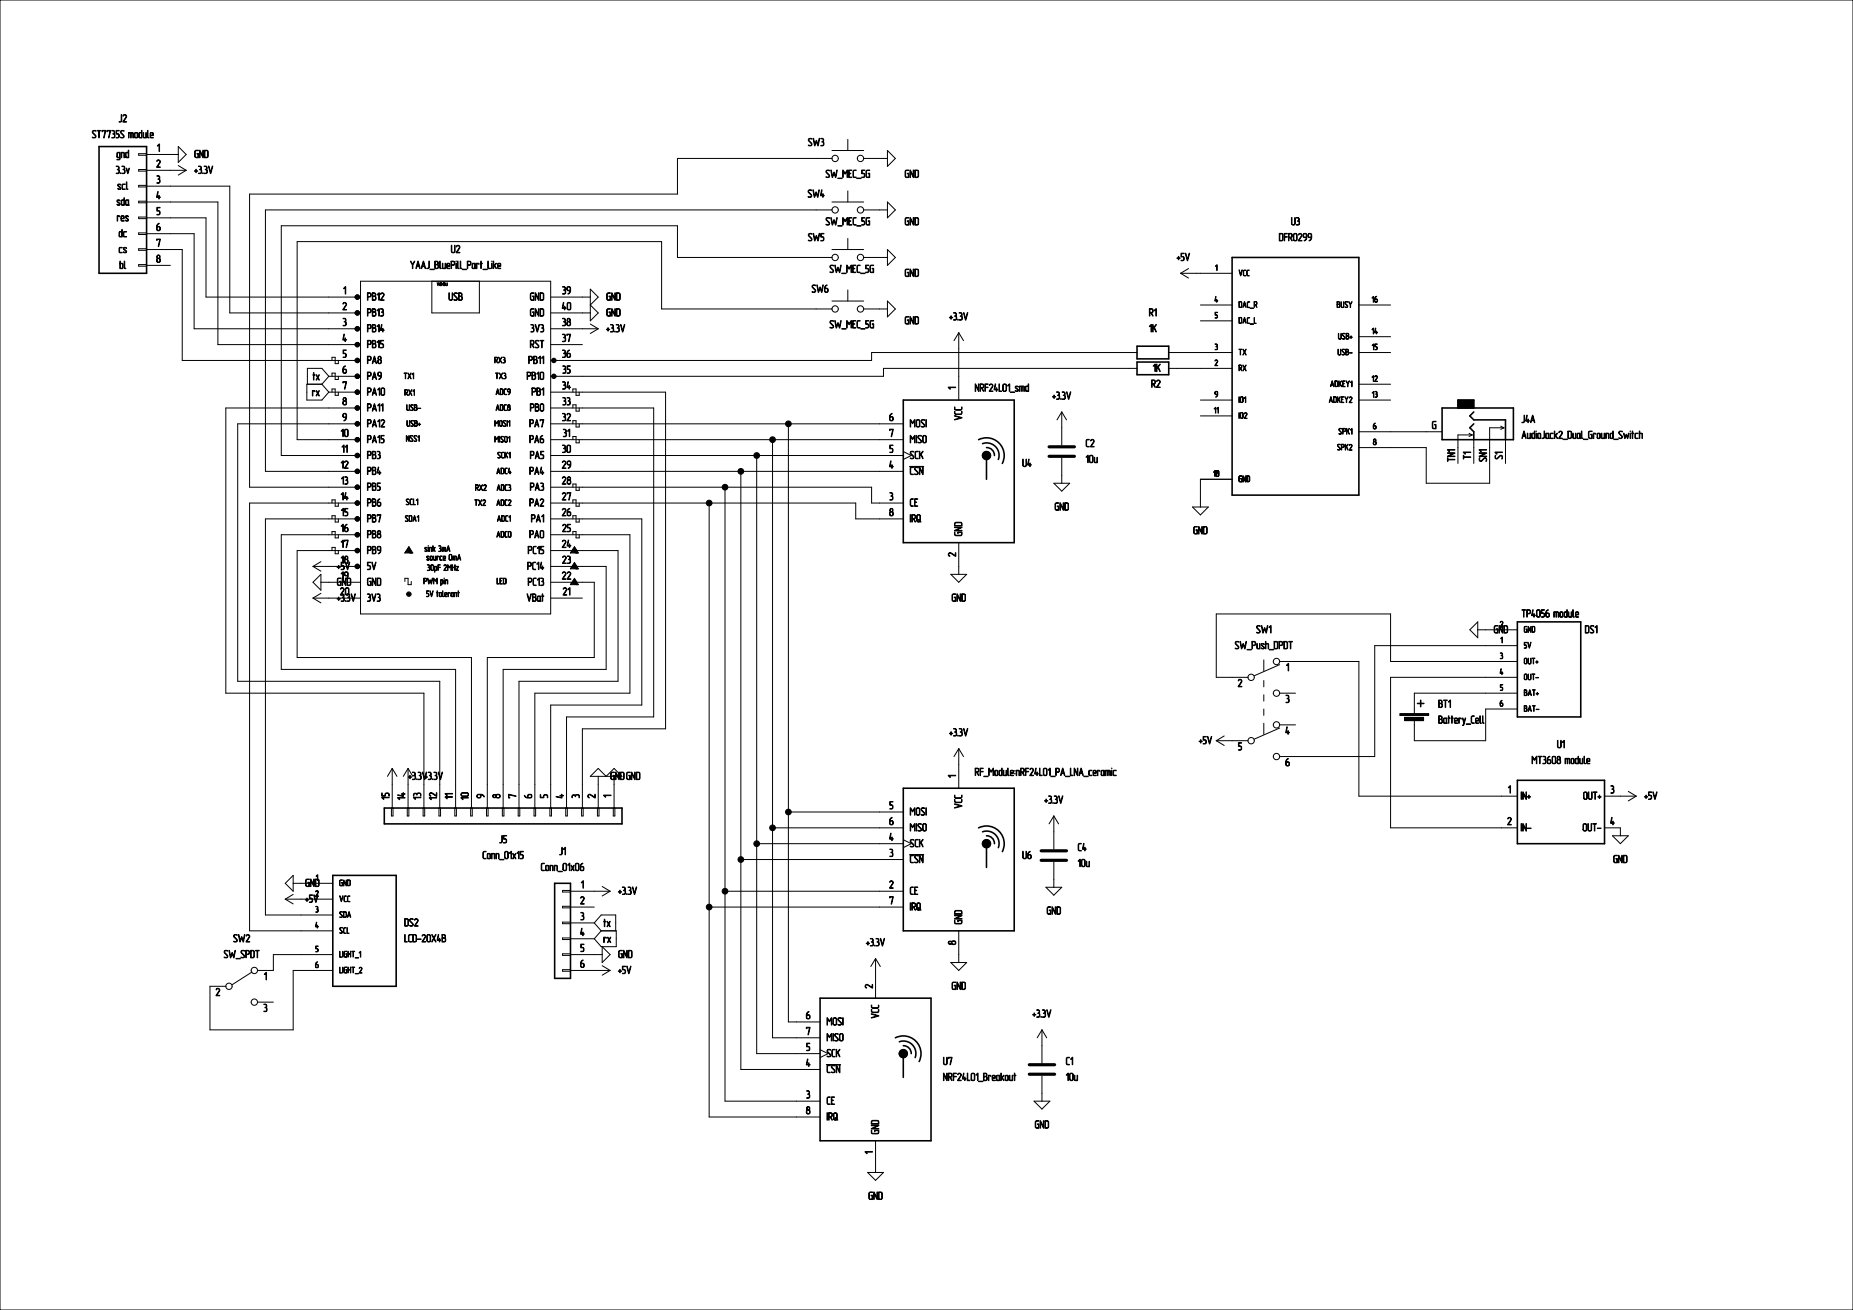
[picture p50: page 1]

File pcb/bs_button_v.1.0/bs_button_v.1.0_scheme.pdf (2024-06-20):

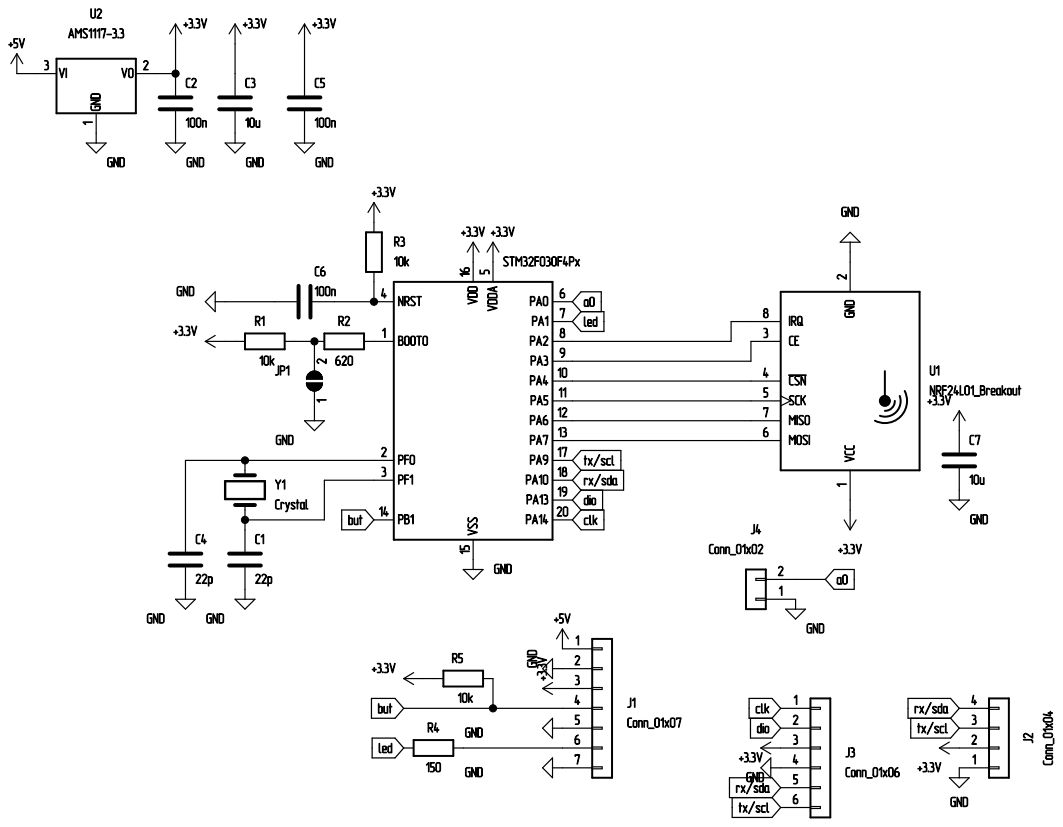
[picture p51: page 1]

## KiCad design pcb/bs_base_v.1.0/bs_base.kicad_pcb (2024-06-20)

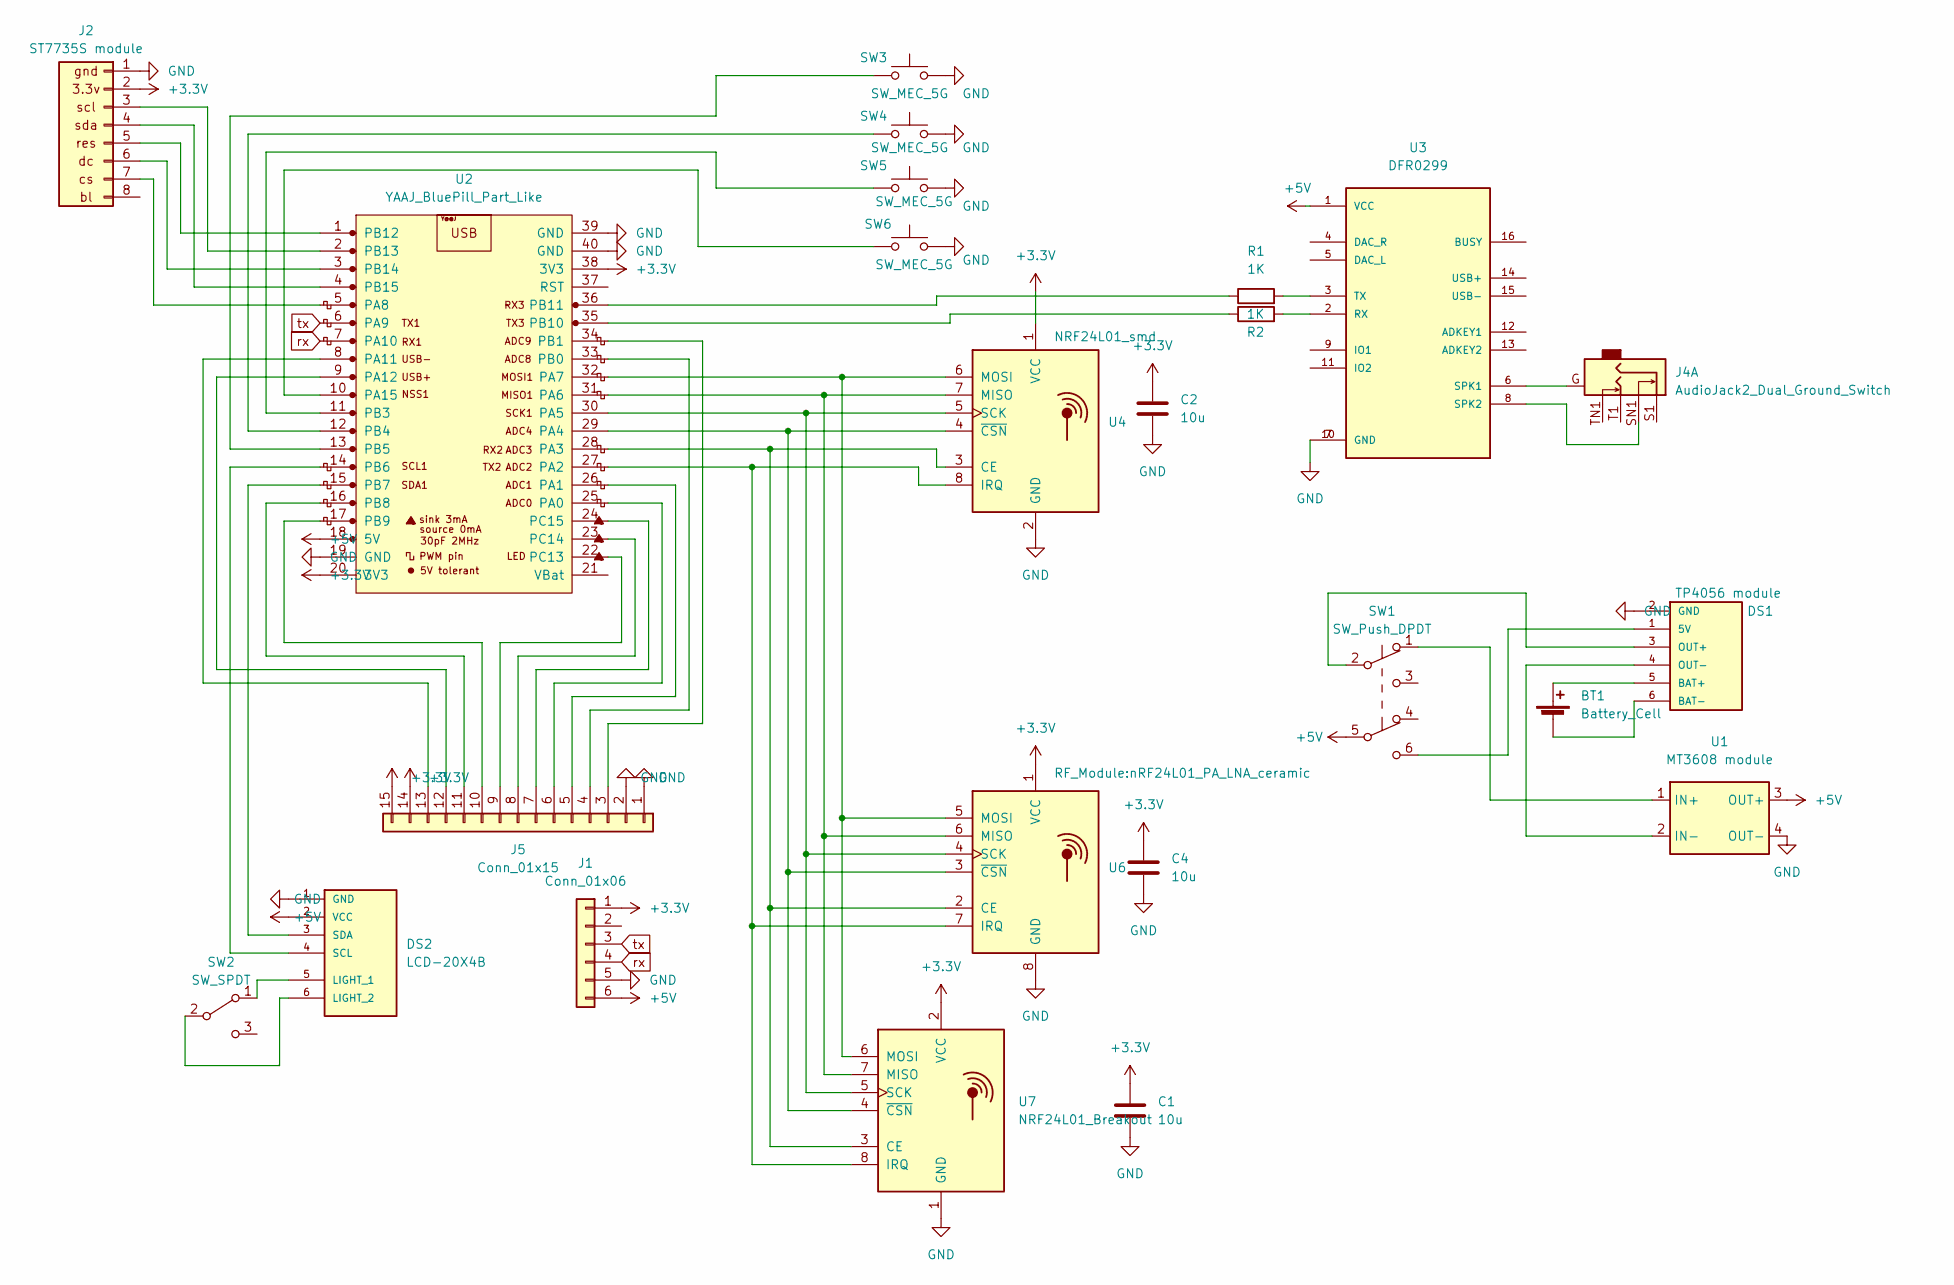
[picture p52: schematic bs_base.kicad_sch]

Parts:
BT1: Battery_Cell; PinHeader_1x02_P2.54mm_Vertical
C1, C2, C4: 10u; C_0805_2012Metric_Pad1.18x1.45mm_HandSolder
DS1: TP4056 module; TP4056-18650; PARTREV N/A
DS2: LCD-20X4B; LCD_LCD-20X4B_i2c; PARTREV N/A
J1: Conn_01x06; PinHeader_1x06_P2.54mm_Vertical
J2: ST7735S module; st7735s module
J4: AudioJack2_Dual_Ground_Switch; Jack_3.5mm_CUI_SJ1-3525N_Horizontal
J5: Conn_01x15; PinHeader_1x15_P2.54mm_Vertical
R1, R2: 1K; R_0805_2012Metric_Pad1.20x1.40mm_HandSolder
SW1: SW_Push_DPDT; SW_Push_2P2T_Toggle_CK_PVA2xxH1xxxxxxV2
SW2: SW_SPDT; SW_Slide_1P2T_CK_OS102011MS2Q
SW3, SW4, SW5, SW6: SW_MEC_5G; SW_PUSH_6mm_H13mm
U1: MT3608 module
U2: YAAJ_BluePill_Part_Like; YAAJ_BluePill_1
U3: DFR0299; MODULE_DFR0299
U4: NRF24L01_smd; NRF24L01-Module-SMD
U6: RF_Module:nRF24L01_PA_LNA_ceramic; nRF24L01_PA_LNA_Breakout_smd
U7: NRF24L01_Breakout; nRF24L01_PA_LNA_Breakout

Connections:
+3V3: C1.1, C2.1, C4.1, J1.1, J2.2, J5.14, J5.15, U2.20 (3V3), U2.38 (3V3), U4.1 (VCC), U6.1 (VCC), U7.2 (VCC)
+5V: DS2.2 (VCC), J1.6, SW1.5 (B), U1.3 (OUT+), U2.18 (5V), U3.1 (VCC)
GND: C1.2, C2.2, C4.2, DS1.2 (GND), DS2.1 (GND), J1.5, J2.1, J5.1, J5.2, SW3.1 (A), SW4.1 (A), SW5.1 (A), SW6.1 (A), U1.4 (OUT-), U2.19 (GND), U2.39 (GND), U2.40 (GND), U3.7 (GND), U3.10 (GND), U4.2 (GND), U6.8 (GND), U7.1 (GND)
unnamed: BT1.1 (+), DS1.5 (BAT+)
unnamed: BT1.2 (-), DS1.6 (BAT-)
unnamed: DS1.1 (5V), SW1.6 (C)
unnamed: DS1.3 (OUT+), SW1.2 (B)
unnamed: DS1.4 (OUT-), U1.2 (IN-)
unnamed: DS2.5 (LIGHT_1), SW2.1 (A)
unnamed: DS2.6 (LIGHT_2), SW2.2 (B)
unnamed: DS2.4 (SCL), U2.14 (PB6)
unnamed: DS2.3 (SDA), U2.15 (PB7)
unnamed: J2.3, U2.2 (PB13)
unnamed: J2.4, U2.4 (PB15)
unnamed: J2.5, U2.1 (PB12)
unnamed: J2.6, U2.3 (PB14)
unnamed: J2.7, U2.5 (PA8)
unnamed: J5.3, U2.34 (PB1)
unnamed: J5.4, U2.33 (PB0)
unnamed: J5.5, U2.26 (PA1)
unnamed: J5.6, U2.25 (PA0)
unnamed: J5.7, U2.24 (PC15)
unnamed: J5.8, U2.23 (PC14)
unnamed: J5.9, U2.22 (PC13)
unnamed: J5.10, U2.17 (PB9)
unnamed: J5.11, U2.16 (PB8)
unnamed: J5.12, U2.9 (PA12)
unnamed: J5.13, U2.8 (PA11)
unnamed: SW3.2 (B), U2.13 (PB5)
unnamed: SW4.2 (B), U2.12 (PB4)
unnamed: SW5.2 (B), U2.11 (PB3)
unnamed: SW6.2 (B), U2.10 (PA15)
unnamed: SW1.1 (A), U1.1 (IN+)
unnamed: U2.27 (PA2), U4.8 (IRQ), U6.7 (IRQ), U7.8 (IRQ)
unnamed: U2.28 (PA3), U4.3 (CE), U6.2 (CE), U7.3 (CE)
unnamed: U2.29 (PA4), U4.4 (~CSN), U6.3 (~CSN), U7.4 (~CSN)
unnamed: U2.30 (PA5), U4.5 (SCK), U6.4 (SCK), U7.5 (SCK)
unnamed: U2.31 (PA6), U4.7 (MISO), U6.6 (MISO), U7.7 (MISO)
unnamed: U2.32 (PA7), U4.6 (MOSI), U6.5 (MOSI), U7.6 (MOSI)
unnamed: R2.1, U2.35 (PB10)
unnamed: R1.1, U2.36 (PB11)
unnamed: R2.2, U3.2 (RX)
unnamed: J4.G, U3.6 (SPK1)
unnamed: J4.SN1, U3.8 (SPK2)
unnamed: R1.2, U3.3 (TX)
rx: J1.4, U2.7 (PA10)
tx: J1.3, U2.6 (PA9)

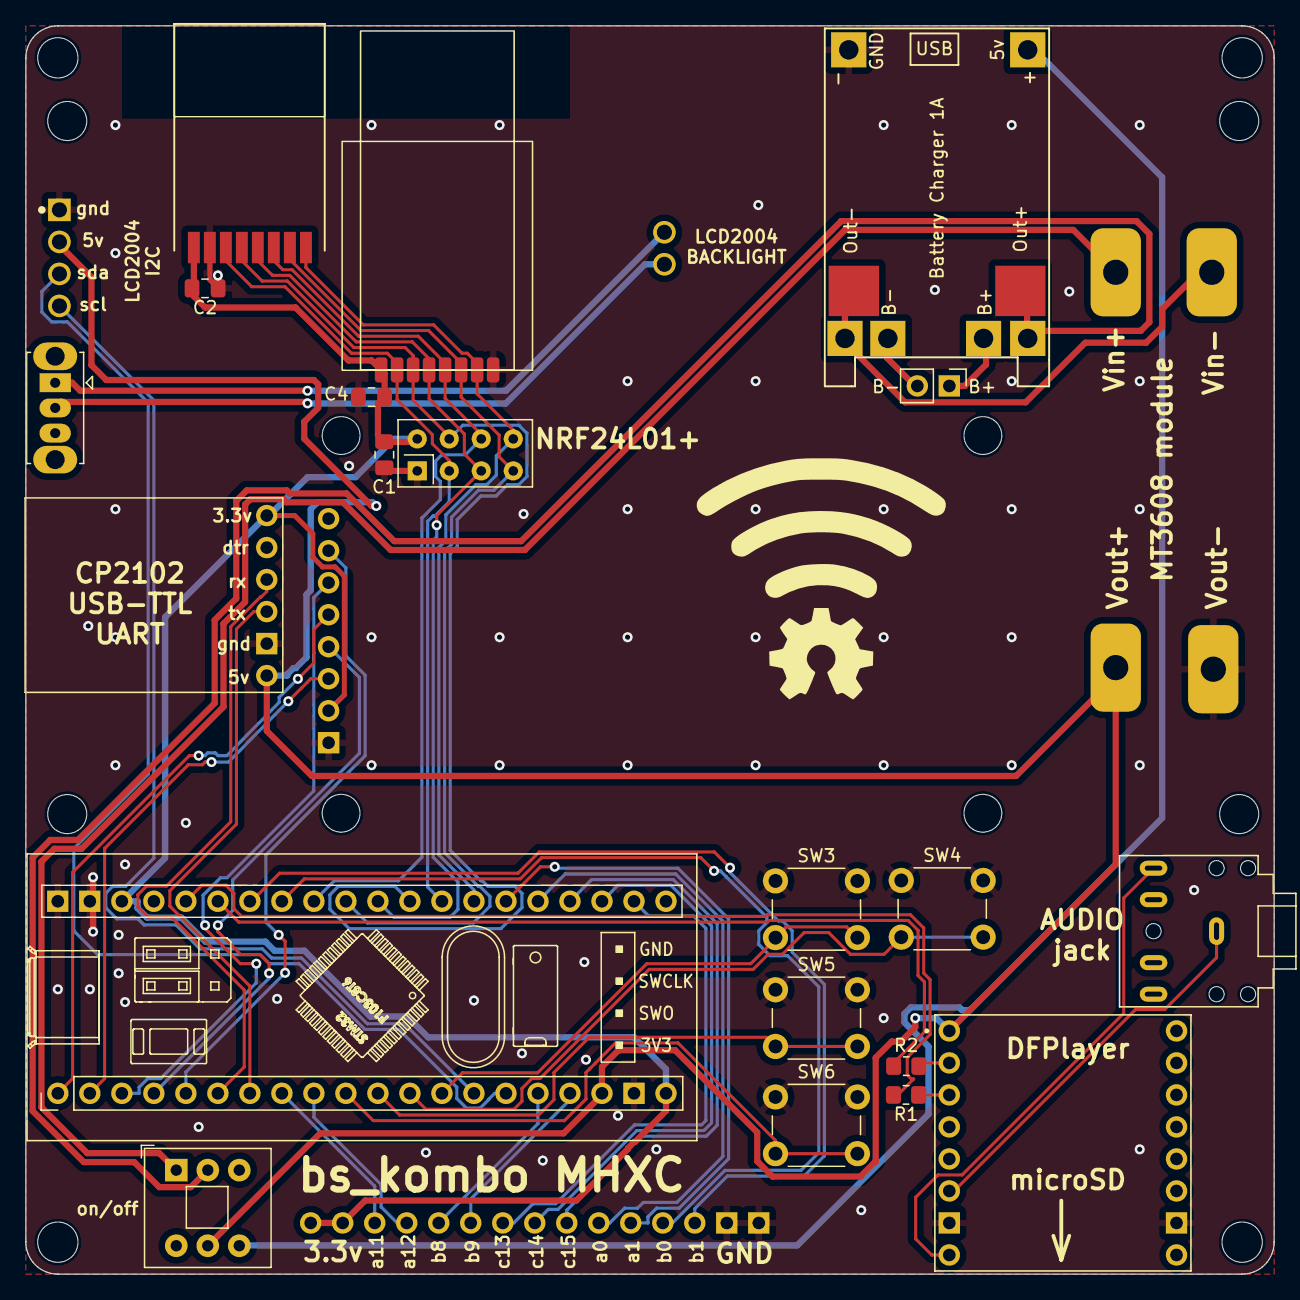
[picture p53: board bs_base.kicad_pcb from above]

Board: 2 copper layers, 99.1 x 99.1 mm, 24 parts (0 on the bottom side), 47 nets.

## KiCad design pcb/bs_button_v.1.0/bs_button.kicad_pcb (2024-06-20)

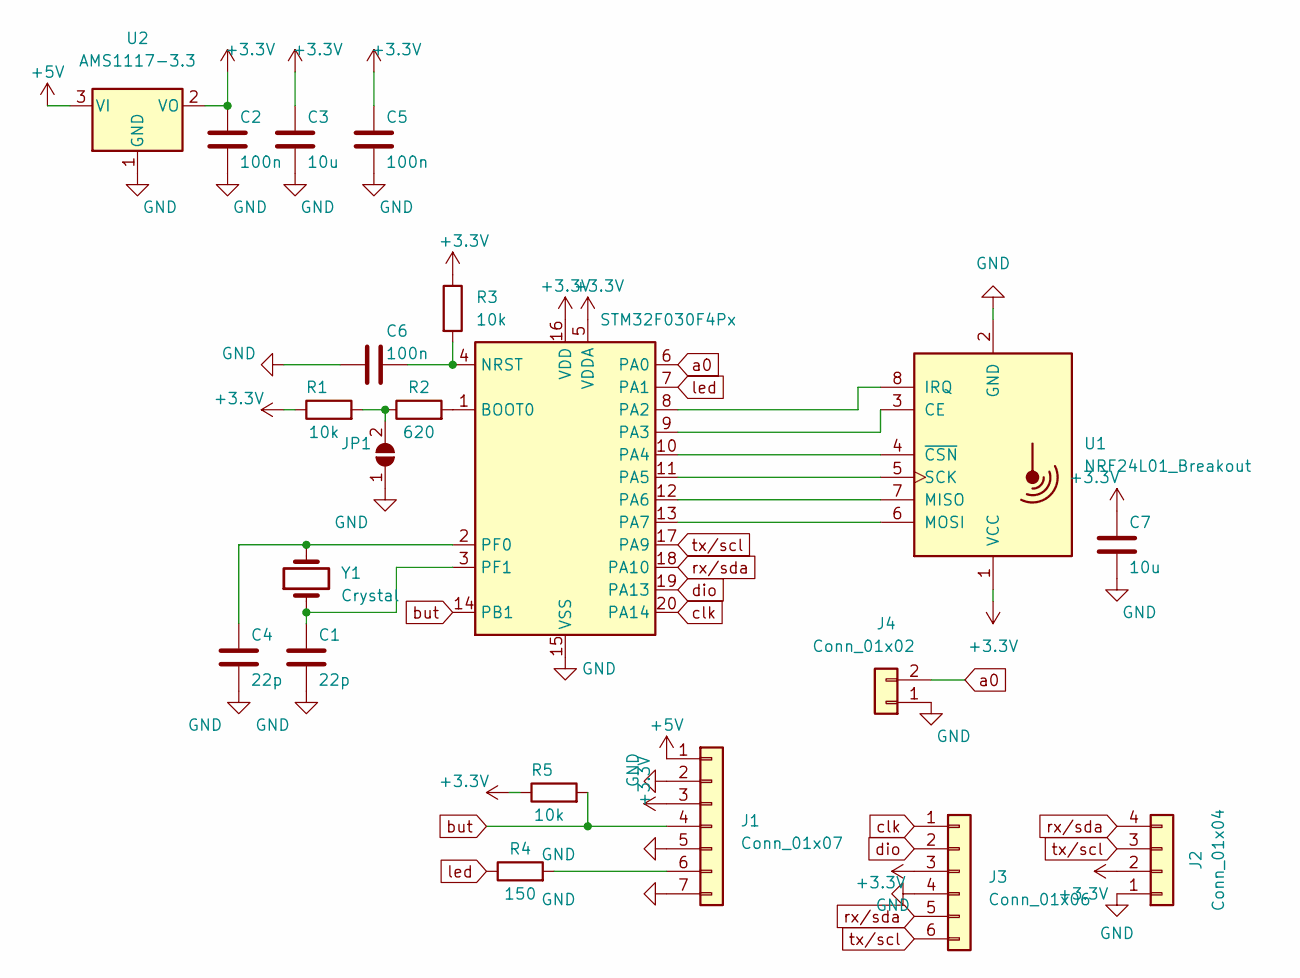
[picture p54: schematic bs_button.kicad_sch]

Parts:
C1, C4: 22p; C_0805_2012Metric_Pad1.18x1.45mm_HandSolder
C2, C5, C6: 100n; C_0805_2012Metric_Pad1.18x1.45mm_HandSolder
C3, C7: 10u; C_0805_2012Metric_Pad1.18x1.45mm_HandSolder
J1: Conn_01x07; PinHeader_1x07_P2.54mm_Vertical
J2: Conn_01x04; PinHeader_1x04_P2.54mm_Vertical
J3: Conn_01x06; PinHeader_1x06_P2.54mm_Vertical
J4: Conn_01x02; PinHeader_1x02_P2.54mm_Vertical
JP1: SolderJumper_2_Open; SolderJumper-2_P1.3mm_Open_TrianglePad1.0x1.5mm
R1, R3, R5: 10k; R_0805_2012Metric_Pad1.20x1.40mm_HandSolder
R2: 620; R_0805_2012Metric_Pad1.20x1.40mm_HandSolder
R4: 150; R_0805_2012Metric_Pad1.20x1.40mm_HandSolder
U1: NRF24L01_Breakout; NRF24L01-Module-SMD
U2: AMS1117-3.3; SOT-223-3_TabPin2
U3: STM32F030F4Px; TSSOP-20_4.4x6.5mm_P0.65mm
Y1: Crystal; Crystal_HC49-U_Vertical

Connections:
+3V3: C2.1, C3.1, C5.1, C7.1, J1.3, J2.2, J3.3, R1.1, R3.1, R5.1, U1.1 (VCC), U2.2 (VO), U3.5 (VDDA), U3.16 (VDD)
+5V: J1.1, U2.3 (VI)
GND: C1.2, C2.2, C3.2, C4.2, C5.2, C6.2, C7.2, J1.2, J1.5, J1.7, J2.1, J3.4, J4.1, JP1.1 (A), U1.2 (GND), U2.1 (GND), U3.15 (VSS)
unnamed: J1.6, R4.2
unnamed: JP1.2 (B), R1.2, R2.1
unnamed: U1.3 (CE), U3.9 (PA3)
unnamed: U1.8 (IRQ), U3.8 (PA2)
unnamed: U1.7 (MISO), U3.12 (PA6)
unnamed: U1.6 (MOSI), U3.13 (PA7)
unnamed: U1.5 (SCK), U3.11 (PA5)
unnamed: U1.4 (~CSN), U3.10 (PA4)
unnamed: R2.2, U3.1 (BOOT0)
unnamed: C6.1, R3.2, U3.4 (NRST)
unnamed: C4.1, U3.2 (PF0), Y1.2
unnamed: C1.1, U3.3 (PF1), Y1.1
a0: J4.2, U3.6 (PA0)
but: J1.4, R5.2, U3.14 (PB1)
clk: J3.1, U3.20 (PA14)
dio: J3.2, U3.19 (PA13)
led: R4.1, U3.7 (PA1)
rx/sda: J2.4, J3.5, U3.18 (PA10)
tx/scl: J2.3, J3.6, U3.17 (PA9)

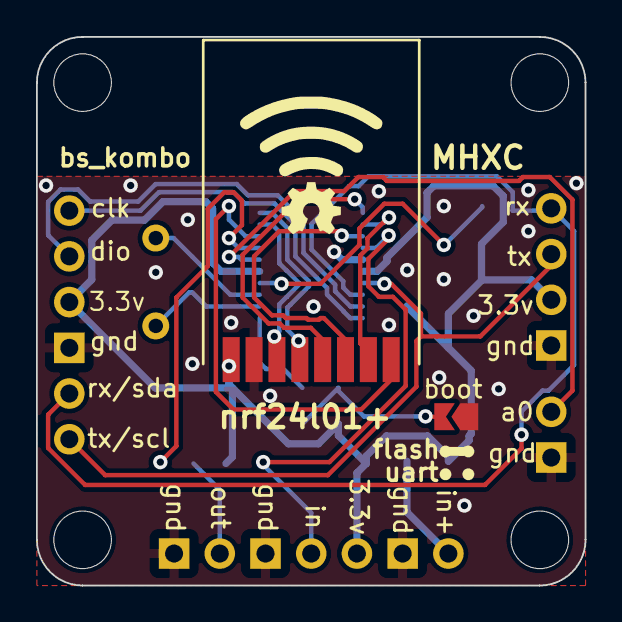
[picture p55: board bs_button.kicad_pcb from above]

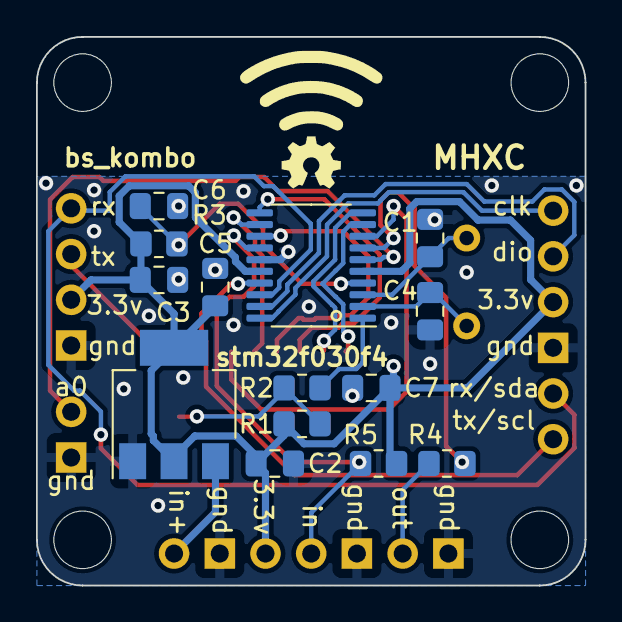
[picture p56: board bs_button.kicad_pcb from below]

Board: 2 copper layers, 30.5 x 30.5 mm, 21 parts (14 on the bottom side), 22 nets.

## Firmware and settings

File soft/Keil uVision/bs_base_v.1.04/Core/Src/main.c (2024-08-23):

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
/* Includes ------------------------------------------------------------------*/
#include "main.h"
#include "i2c.h"
#include "iwdg.h"
#include "spi.h"
#include "tim.h"
#include "usart.h"
#include "gpio.h"


/* USER CODE BEGIN PV */

//переменные и массивы
char str[STRING_SIZE]								= {0};				//строка для вывода в порт
char input_str[STRING_SIZE] 				= {0};				//входящая строка 
char char_to_send[NUM_OF_SLAVES] 		= CHARS_LIST;	//массив символов для отправки в порт
uint8_t slave_addrs[NUM_OF_SLAVES] 	= ADRESS_LIST;//массив адресов
uint8_t slave_nums[NUM_OF_SLAVES] 	= NUM_LIST;		//массив номеров

//строки для вывода на дисплей LCD2004
#if NUM_OF_SLAVES == 20

char string_0[] 	= "0123456789abcdefghij";
char string_1[] 	= "                    ";
char string_2[] 	= "                    ";
char string_3[] 	= "            BS KomBO";

#elif NUM_OF_SLAVES == 6

char string_0[] 	= "  1  2  3  4  5  6  ";
char string_1[] 	= "                    ";
char string_2[] 	= "                    ";
char string_3[] 	= "            BS KomBO";

#endif

//строки для вывода на дисплей st7735
char w_string_1[] = "          ";
char w_string_2[] = "          ";

//внешние переменные для работы с радиомодулем
extern uint8_t 					tx_buf[TX_PLOAD_WIDTH];	//буфер передачи
extern uint8_t 					rx_buf[TX_PLOAD_WIDTH];	//буфер приема
extern volatile uint8_t f_rx, f_tx;							//флаги приема и передачи

//структура флагов устройства
volatile Flags_t 			flags;
volatile Variables_t 	vars;

//массив структур данных кнопок
B_data_t							b_data[NUM_OF_SLAVES];

//структура для преобразования данных
float_to_byte_t 			float_to_byte;

/* USER CODE END PV */

void SystemClock_Config(void);
/* USER CODE BEGIN 0 */

//Процедура инициализации переменных, флагов, массивов
void init_variables(void)
{
	flags.rst_push 					= 0;
	flags.nxt_push 					= 0;
	flags.set_push 					= 0;
	flags.time_push 				= 0;
	flags.f_timer 					= 0;
	
	vars.seconds 						= 0;
	vars.temp_seconds 			= 0;
	vars.millis 						= 0;
	vars.slave_counter 			= 0;
	vars.send_order_count		= 1;
	vars.bounce_count = 0;
	
	for (uint8_t i = 0; i < NUM_OF_SLAVES; i++)
	{
		b_data[i].number 			= i;
		b_data[i].address 		= slave_addrs[i];
		b_data[i].time 				= MAX_TIME;
		b_data[i].cmd 				= LED_STAT; 
		b_data[i].led_status 	= LED_STAT_OFF; 
		b_data[i].push_order 	= 0;
		b_data[i].pushed 			= 0;
	}
}

//Процедура расчета контрольной суммы
uint16_t crc16_calc(volatile uint8_t buf[], uint8_t buf_size) 
{
	uint16_t	crc = 0;			// возвращаемое значение
	uint16_t	D;						// �?ндекс элемента массива для наложения 
	int16_t 	T;						// Элемент массива для наложения, вычисляется на лету
	uint16_t	P = 0x1021;		// Полином - маска

	for (uint8_t i = 0; i < buf_size; i++)
	{
		D = crc >> 8; 				// Сдвиг crc на 8 бит вправо
		D = D ^ buf[i];				// Вычисление индекса элемента массива для наложения  

		T = D;								// Вычисление элемента массива
		T = T << 8;        		// Сдвиг элемента массива на 8 бит влево

		for (uint8_t j = 0; j < 8; j++)    // Повторение 8 раз
		{
			if (T < 0)					// Если старший бит = 1
			{
				T = T << 1;				// Сдвиг элемента массива на 1 бит влево
				T = T ^ P;				// Наложение полинома
			}
			else
			{
				T = T << 1;				// Сдвиг элемента массива на 1 бит влево
			}
		}
		crc = crc << 8;				// Сдвиг С на 8 бит влево
		crc = crc ^ T;				// �?сключающе или между С и элементом массива
	}

	return crc;							// Возврат значения crc
}

//Процедура приема радиомодуля
void nrf24l01_receive(void)
{
	if(f_rx)	//если флаг приема поднят (флаг поднимается по внешнему прерыванию от радиомодуля)
	{
		uint16_t temp_crc = crc16_calc(rx_buf, TX_PLOAD_WIDTH - 2);
		uint16_t input_crc = (uint16_t)rx_buf[TX_PLOAD_WIDTH - 1] + (uint16_t)(rx_buf[TX_PLOAD_WIDTH - 2] << 8);
		if (temp_crc == input_crc)
		{
			for (uint8_t i = 0; i < NUM_OF_SLAVES; i++)
			{	//если найден принятый адрес
				if (rx_buf[0] == slave_addrs[i]) 	//если найден принятый адрес
				{
					float_to_byte.char_val[0] = rx_buf[5];
					float_to_byte.char_val[1] = rx_buf[6];
					float_to_byte.char_val[2] = rx_buf[7];
					float_to_byte.char_val[3] = rx_buf[8];
					b_data[i].vcc = float_to_byte.float_val;
					
					if ((*(uint32_t*)&rx_buf[1]) != NOT_PUSHED)
					{	
						uint32_t time = *(uint32_t*)&rx_buf[1];	//преобразуем оставшиеся байты во время

						if (b_data[i].pushed == 0)
						{
							b_data[i].time = time;
						}
					}	
					break;
				}
			}
		}
		f_rx = 0;					//опускаем флаг приема
	}
}

//Процедура обновления дисплея
void refresh_display()
{
	#ifdef LCD_2004
		LCD_Clear();

		LCD_SetPos(0,0);
		LCD_String(string_0);
		LCD_SetPos(0,1);
		LCD_String(string_1);
		LCD_SetPos(0,2);
		LCD_String(string_2);
		LCD_SetPos(0,3);
		LCD_String(string_3);
	#endif
	


	#ifdef ST_7735

		#if NUM_OF_SLAVES == 20

		ST7735_FillScreen(ST7735_BLACK);
	
		ST7735_Write_W_String(0, 0,  "0123456789", Font_11x18, ST7735_WHITE, ST7735_BLACK);
		ST7735_Write_W_String(0, 50, "abcdefghij", Font_11x18, ST7735_WHITE, ST7735_BLACK);
	
		ST7735_WriteString(100, 120, "BS KomBO", Font_7x10, ST7735_WHITE, ST7735_BLACK);

		#elif NUM_OF_SLAVES == 6

		ST7735_FillScreen(ST7735_BLACK);

		ST7735_Write_W_String(0, 0,  "  1  2  3  ", Font_11x18, ST7735_WHITE, ST7735_BLACK);
		ST7735_Write_W_String(0, 50, "  4  5  6  ", Font_11x18, ST7735_WHITE, ST7735_BLACK);

		ST7735_WriteString(100, 120, "BS KomBO", Font_7x10, ST7735_WHITE, ST7735_BLACK);

		#endif

	#endif

	}

//Процедура инициализации дисплея
void display_init(void)
{
	#ifdef LCD_2004
		LCD_init();
	#endif
	
	#ifdef ST_7735
		ST7735_Init();
		ST7735_FillScreen(ST7735_BLACK);
	#endif
}

//Подпрограмма тестирования радиомодуля
uint8_t nrf_test(void)
{
	uint8_t buf_0[TX_ADR_WIDTH] = {0};				
	uint8_t buf_1[TX_ADR_WIDTH] = {0};
	uint8_t test_addr_0[TX_ADR_WIDTH] = UNIQUE_ADDRESS_0;
	uint8_t test_addr_1[TX_ADR_WIDTH] = UNIQUE_ADDRESS_1;
	
	uint8_t err = ERR_OK;								

	//читаем значения регистров
	
	#ifdef MASTER
		nrf24_read_buf(RX_ADDR_P1,buf_0,3);	
		nrf24_read_buf(TX_ADDR,buf_1,3);
	#endif
	
	#ifdef SLAVE
		nrf24_read_buf(RX_ADDR_P1,buf_1,3);	
		nrf24_read_buf(TX_ADDR,buf_0,3);
	#endif
	
	sprintf(str, "TX_ADDR: 0x%02X, 0x%02X, 0x%02X\r\nRX_ADDR: 0x%02X, 0x%02X, 0x%02X\r\n",
	buf_1[0], buf_1[1], buf_1[2], buf_0[0], buf_0[1], buf_0[2]);
	
	#ifdef DEBUG_MODE
		usart_print(str);	
	#endif
	
	//проверяем значения регистров записанных при инициализации и считанных 
	
	for (uint8_t i = 0; i < TX_ADR_WIDTH; i++)
	{
		if (test_addr_0[i] != buf_0[i]) err = NRF_ERR;
		if (test_addr_1[i] != buf_1[i]) err = NRF_ERR;
	}
	
	return err;
}

//Процедура тестирования радиомодуля и сигнализации
void test_and_info(uint8_t err)
{
	sprintf(str, "v. %d.%02d", VERSION, SUBVERSION);
	
	#ifdef DEBUG_MODE
		usart_println(DEV_INFO);
		usart_println(str);
	#endif
	
	#ifdef LCD_2004
		LCD_SetPos(0,0);
		LCD_String(DEV_INFO);
		LCD_SetPos(0,1);
		LCD_String(str);
	#endif
	
	#ifdef ST_7735
		ST7735_WriteString(0, 0, DEV_INFO, Font_11x18, ST7735_WHITE, ST7735_BLACK);
		ST7735_WriteString(0, 20, str, Font_11x18, ST7735_WHITE, ST7735_BLACK);
	#endif
	
	#ifdef DEBUG_MODE
		usart_println(str);
	#endif	
	
	#ifndef DEBUG_MODE
	LL_IWDG_ReloadCounter(IWDG);
	#endif
	
	err = nrf_test();		//выводим значения регистров в порт
	
	if (err == ERR_OK) 
	{
		sprintf(str, "%s ch = %d", "nrf24 OK ", CHANNEL);
		
		#ifdef DEBUG_MODE
			usart_println(str);
		#endif		
		
		#ifdef LCD_2004
			LCD_SetPos(0,2);
			LCD_String(str);
		#endif
		
		#ifdef ST_7735
			ST7735_WriteString(0, 60, "nrf24 OK", Font_11x18, ST7735_WHITE, ST7735_BLACK);
			sprintf(str, "ch = %d", CHANNEL);
			ST7735_WriteString(0, 80, str, Font_11x18, ST7735_WHITE, ST7735_BLACK);
		#endif
	}
	else  if (err == NRF_ERR) 
	{
		#ifdef DEBUG_MODE
			usart_println("nrf ERROR");
		#endif			
		
		#ifdef LCD_2004
			LCD_SetPos(0,2);
			LCD_String("nrf ERROR");
		#endif
		
		#ifdef ST_7735
			ST7735_WriteString(0, 60, "nrf24 ERROR", Font_11x18, ST7735_WHITE, ST7735_BLACK);
		#endif
	}
}

//Процедура сортировки данных по возрастанию
void sort_data(uint32_t *data) 
{
	for(uint8_t i = 0 ; i < NUM_OF_SLAVES - 1; i++) 
	{ 
		for(uint8_t j = 0 ; j < NUM_OF_SLAVES - i - 1 ; j++) 
		{
			if(data[j] > data[j+1]) 			//сравниваем два соседних элемента.
			{           									//если они идут в неправильном порядке, то  
				uint32_t tmp = data[j];			//меняем их местами. 
        data[j] = data[j+1];
        data[j+1] = tmp; 
      }
    }
  }
}

//Процедура инициализации модуля DWT
void dwt_init(void)
{
	SCB_DEMCR |= CoreDebug_DEMCR_TRCENA_Msk; // разрешаем использовать счётчик
	DWT_CONTROL |= DWT_CTRL_CYCCNTENA_Msk;   // запускаем счётчик
}

//Процедура микросекундной задержки
void delay_us(uint32_t us)
{
	uint32_t us_count_tic =  us * (SystemCoreClock / 1000000); // получаем кол-во тактов за 1 мкс и умножаем на наше значение
	DWT->CYCCNT = 0U; // обнуляем счётчик
	while(DWT->CYCCNT < us_count_tic);
}

//Процедура отправки общей команды сброса
void reset_all(void)
{
	tx_buf[0] = RESET_CMD;	//
	
	uint16_t temp_crc = crc16_calc(tx_buf, TX_PLOAD_WIDTH - 2);
	
	tx_buf[TX_PLOAD_WIDTH - 2] = (uint8_t)(temp_crc >> 8);
	tx_buf[TX_PLOAD_WIDTH - 1] = (uint8_t)temp_crc;
	
	nrf24_send(tx_buf);						//отправляем посылку в эфир
}

//Процедура псевдослучайного перемешивания данных
void data_mix(uint8_t *data)
{
	uint8_t temp_data[NUM_OF_SLAVES];
	uint8_t i_rnd;
	
	//прибавляем ко всем элементам 1 потому что алгоритм предполагает отсутствие нулей
	for(uint8_t i = 0; i < NUM_OF_SLAVES; i++) 
	{
			if (data[i] != 0xFF) data[i] = data[i] + 1;
	}
	
	for(uint8_t i = 0 ; i < NUM_OF_SLAVES; i++) 
	{
		i_rnd = rand()%NUM_OF_SLAVES;	//генерируем случайный индекс
		
		while (data[i_rnd] == 0)			//в случае если элемент массива с полученным индексом нулевой
		{
				i_rnd = rand()%NUM_OF_SLAVES;		//генерируем новый случайный индекс пока не найдем ненулевой элемент
		}
		if (data[i_rnd] != 0)					
		{
				temp_data[i] = data[i_rnd];	//записываем случайный элемент массива во временный массив
				data[i_rnd] = 0;						//обнуляем сохраненный элемент
		}
	}
	
	//копируем перемешанные элементы массива обратно в исходный массив, вычитаем единицу
	for(uint8_t i = 0; i < NUM_OF_SLAVES; i++) 
	{
			if (data[i] != 0xFF) data[i] = temp_data[i] - 1;
	}
}

//Процедура реализации команды "сброс"
void rst_push(void)
{
	reset_all();		//отправляем команду общего сброса всем кнопкам
	
	f_rx = 0;					//опускаем флаг приема

	//приводим в исходное состояние дисплей
	#ifdef LCD_2004
		LCD_Clear();
		refresh_display();
	#endif
	
	#ifdef ST_7735
		refresh_display();
		for (uint8_t i = 0; i < 10; i++)
		{
			w_string_1[i] = ' ';
			w_string_2[i] = ' ';
		}
	#endif
	
	//перемешаваем массив с номерами кнопок
	data_mix(slave_nums);
	//приводим все переменные в исходное состояние
	init_variables();
	//делаем паузу
	LL_mDelay(SCAN_PERIOD * 5);
}

//Процедура команды "установка"
void set_push(void)
{
	//присваиваем новое значение переключателя звуковых файлов
	vars.sound_switch++;			
	if (vars.sound_switch >= 5) vars.sound_switch = 0;
	
	//отображаем на дисплее название нового звука
	#ifdef LCD_2004
		switch (vars.sound_switch)
		{
			case 0:
				LCD_SetPos(12,2);
				LCD_String("shoot   ");
			break;
			case 1:
				LCD_SetPos(12,2);
				LCD_String("open    ");
			break;
			case 2:
				LCD_SetPos(12,2);
				LCD_String("svist   ");
			break;
			case 3:
				LCD_SetPos(12,2);
				LCD_String("falstart");
			break;
			case 4:
				LCD_SetPos(12,2);
				LCD_String("zvon    ");
			break;
		}
	#endif
	
	#ifdef ST_7735
		switch (vars.sound_switch)
		{
			case 0:
				ST7735_WriteString(0, 90, "shoot   ", Font_7x10, ST7735_WHITE, ST7735_BLACK);
			break;
			case 1:
				ST7735_WriteString(0, 90, "open    ", Font_7x10, ST7735_WHITE, ST7735_BLACK);
			break;
			case 2:
				ST7735_WriteString(0, 90, "svist   ", Font_7x10, ST7735_WHITE, ST7735_BLACK);
			break;
			case 3:
				ST7735_WriteString(0, 90, "falstart", Font_7x10, ST7735_WHITE, ST7735_BLACK);
			break;
			case 4:
				ST7735_WriteString(0, 90, "zvon    ", Font_7x10, ST7735_WHITE, ST7735_BLACK);
			break;
		}
	#endif

}

//Процедура выполнения команды "время"
void time_push(void)
{
	flags.f_timer = 1;		//поднимаем флаг таймера
	vars.seconds = 0;			//обнуляем счетчик секунд
	//Выводим на дисплей значение времени
	#ifdef LCD_2004
		LCD_SetPos(0,2);
		LCD_String(string_2);	//очищаем строку
		sprintf(str, "%02d:%02d", (uint8_t)vars.seconds/60, (uint8_t)vars.seconds%60);
		LCD_SetPos(0,2);
		LCD_String(str);
	#endif
	
	#ifdef ST_7735
		sprintf(str, "%02d:%02d", vars.seconds/60, vars.seconds%60);
		ST7735_WriteString(0, 110, str, Font_11x18, ST7735_WHITE, ST7735_BLACK);
	#endif
	//воспроизводим нужный звуковой айл
	mp3_play(MP3_START);
}

//Процедура формирования очереди нажатий
void order_processing(void)
{
	uint32_t time_to_sort[NUM_OF_SLAVES];
	//uint32_t buts_to_sort[NUM_OF_SLAVES];
	
	uint8_t flag_order[NUM_OF_SLAVES] = {0};
	
	uint8_t order = 0;
	//uint8_t number = 0;
	
	//копируем времена кнопок для сортировки
	for(uint8_t i = 0 ; i < NUM_OF_SLAVES; i++) 
	{ 
		time_to_sort[i] = b_data[i].time;
	}
	//сортируем времена
	sort_data(time_to_sort);
	
	//находим 
	for(uint8_t i = 0 ; i < NUM_OF_SLAVES; i++) 
	{ 
		for(uint8_t j = 0 ; j < NUM_OF_SLAVES; j++) 
		{ 
			//в качестве индекса номер из перемешанного массива для обеспечения более объективного выбора очередности при совпадении времен
			//если время кнопки сопадает со следующим по величине, точно нажималась и соответствующий флаг учета очереди не поднят
			if ((b_data[slave_nums[j]].time == time_to_sort[i]) && (b_data[slave_nums[j]].time != MAX_TIME) && (!flag_order[slave_nums[j]]) )
			{
				order++;																	//переходим к следующему значению очереди
				b_data[slave_nums[j]].push_order = order;	//присваиваем соответствующий номер в очереди кнопке
				flag_order[slave_nums[j]] = 1;						//поднимаем флаг учета
			}
		}
	}
	
	//отсылаем в последовательный порт символы в нужной последовательности
	for(uint8_t i = 0 ; i < NUM_OF_SLAVES; i++) 
	{ 
		//если номер в очереди соответствует текущему значению счетчика очереди и кнопка нажималась
		if ((b_data[i].push_order == vars.send_order_count) && (b_data[i].time != MAX_TIME))
		{
			sprintf(str,"%c",char_to_send[i]);		
			usart_print(str);					//высылаем символ в порт
			vars.send_order_count++;	//увеличиваем значение счетчика
		}
	}
	
	//расставляем состояния кнопок для отправки и выводим очередь на дисплей
	for(uint8_t i = 0 ; i < NUM_OF_SLAVES; i++) 
	{ 
		if (b_data[i].push_order != 0)
		{
			if (b_data[i].push_order == 1)
			{
				b_data[i].led_status = LED_STAT_TGL;	//первому в очереди - моргать
			}
			else
			{
				b_data[i].led_status = LED_STAT_ON;		//оставшиеся нажатые - зажечь
			}
			//выводим данные на дисплей

			#if NUM_OF_SLAVES == 20

				#ifdef LCD_2004
					LCD_SetPos(b_data[i].number, 1);
					LCD_SendChar(char_to_send[b_data[i].push_order - 1]);
				#endif

				#ifdef ST_7735
					if (i < 10)
					{
						w_string_1[i] = char_to_send[b_data[i].push_order - 1];
						ST7735_Write_W_String(0, 20, w_string_1, Font_11x18, ST7735_YELLOW, ST7735_BLACK);
					}
					else
					{
						w_string_2[i-10] = char_to_send[b_data[i].push_order - 1];
						ST7735_Write_W_String(0, 70, w_string_2, Font_11x18, ST7735_YELLOW, ST7735_BLACK);
					}
				#endif

			#elif NUM_OF_SLAVES == 6

				#ifdef LCD_2004
					LCD_SetPos(b_data[i].number*3 + 2, 1);
					LCD_SendChar(char_to_send[b_data[i].push_order - 1]);
				#endif

				#ifdef ST_7735
					if (i < 4)
					{
						w_string_1[i*3 + 2] = char_to_send[b_data[i].push_order - 1];
						ST7735_Write_W_String(0, 20, w_string_1, Font_11x18, ST7735_YELLOW, ST7735_BLACK);
					}
					else
					{
						w_string_2[i*3 + 2 - 10] = char_to_send[b_data[i].push_order - 1];
						ST7735_Write_W_String(0, 70, w_string_2, Font_11x18, ST7735_YELLOW, ST7735_BLACK);
					}
				#endif

			#endif
			
			

			//воспроизводим звук нажатия в зависимости от состояния таймера и настроек
			if (!b_data[i].pushed)
			{
				b_data[i].pushed = 1;

				if (flags.f_timer)
				{
					mp3_play(MP3_ANSWER);
				}
				else
				{
					switch (vars.sound_switch)
					{
						case 0:
							mp3_play(MP3_SHOOT);
						break;
						case 1:
							mp3_play(MP3_ANSWER);
						break;
						case 2:
							mp3_play(MP3_SVIST);
						break;
						case 3:
							mp3_play(MP3_FALSTART);
						break;
						case 4:
							mp3_play(MP3_ZVON);
						break;
					}
				}
			}
		}
	}
}
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
int main(void)
{

  /* USER CODE BEGIN 1 */
	uint8_t err = ERR_OK;
	//задаем звуковой сигнал по умолчанию
	vars.sound_switch = 0;
  /* USER CODE END 1 */

  /* MCU Configuration--------------------------------------------------------*/

  /* Reset of all peripherals, Initializes the Flash interface and the Systick. */
  HAL_Init();

  /* Configure the system clock */
  SystemClock_Config();

  /* Initialize all configured peripherals */
  MX_GPIO_Init();
  MX_SPI1_Init();
  MX_USART1_UART_Init();
  MX_TIM1_Init();
  MX_I2C1_Init();
  MX_TIM2_Init();
  MX_SPI2_Init();
  MX_USART3_UART_Init();
  //MX_IWDG_Init();
  /* USER CODE BEGIN 2 */
	
	dwt_init();					//инициализируем dwt
	spi_init();					//инициализируем SPI
	nrf24_init();				//инициализируем радиомодуль
	usart_init(103);		//инициализируем USART
	
	display_init();			//инициализируем дисплей

	test_and_info(err);	//тестируем радиомодуль и выводим информацию	
	
	#ifndef DEBUG_MODE
		LL_IWDG_ReloadCounter(IWDG);
	#endif
	
	mp3_init();					//инициализируем звуковой модуль

	refresh_display();	//обновляем дисплей
	
	//разрешаем прерывания, запускаем таймеры
	LL_TIM_EnableIT_UPDATE(TIM1);
	LL_TIM_EnableCounter(TIM1);	
	LL_TIM_EnableIT_UPDATE(TIM2);
	LL_TIM_EnableCounter(TIM2);
	LL_USART_EnableIT_RXNE(USART1);
	
	//инициализируем переменные
	init_variables();
	
	//отправляем команду общего сброса
	reset_all();
	
	//устанавливаем громкость звукового модуля
	mp3_volume(15);

  /* USER CODE END 2 */

  /* Infinite loop */
  /* USER CODE BEGIN WHILE */
  while (1)
  {	
		//проверяем флаг сброса 
		if (flags.rst_push)			//если поднят флаг
		{
			flags.rst_push = 0;		//опускаем флаг
			rst_push();						//выполняем команду "сброс"
		}
		
		//следующий блок выполняется с указанной периодичностью
		if ((vars.millis - vars.temp_millis) > SCAN_PERIOD)
		{
			vars.temp_millis = vars.millis;
			
			tx_buf[0] = b_data[vars.slave_counter].address;	//записываем в буфер очередной адрес
			tx_buf[1] = b_data[vars.slave_counter].cmd;
			tx_buf[2] = b_data[vars.slave_counter].led_status;
			
			uint16_t temp_crc = crc16_calc(tx_buf, TX_PLOAD_WIDTH - 2);
			
			tx_buf[TX_PLOAD_WIDTH - 2] = (uint8_t)(temp_crc >> 8);
			tx_buf[TX_PLOAD_WIDTH - 1] = (uint8_t)temp_crc;
			
			nrf24_send(tx_buf);						//отправляем посылку в эфир

			vars.slave_counter++;
			
			if (vars.slave_counter >= NUM_OF_SLAVES) 
			{
				vars.slave_counter = 0;			
				
				if (flags.nxt_push == 1)
				{
					flags.nxt_push = 2;
					nxt_push();
				}
				
				if (flags.set_push)
				{
					flags.set_push = 0;
					set_push();
				}

				if (flags.time_push)
				{
					flags.time_push = 0;
					time_push();
				}
				
				order_processing();
			}
			
			if (flags.nxt_push == 2)
			{
				vars.bounce_count++;
				if (vars.bounce_count >= BOUNCE_OFFSET)
				{
					vars.bounce_count = 0;
					flags.nxt_push = 0;
				}
			}

			if (flags.f_timer)	//если секундный таймер запущен
			{			
				//если прошла секунда
				if ((vars.seconds - vars.temp_seconds) > 0)
				{
					uint8_t dec = vars.seconds/60;
					uint8_t ed = vars.seconds%60;
					vars.temp_seconds = vars.seconds;
					
					//отображаем текущее время на дисплее
					#ifdef LCD_2004
						sprintf(str, "%02d:%02d", dec, ed);
						LCD_SetPos(0,2);
						LCD_String(str);
					#endif
					
						#ifdef ST_7735
						sprintf(str, "%02d:%02d", vars.seconds/60, vars.seconds%60);
						ST7735_WriteString(0, 110, str, Font_11x18, ST7735_WHITE, ST7735_BLACK);
					#endif
				}
			}
		}

		nrf24l01_receive();		//прием
		
    /* USER CODE END WHILE */

    /* USER CODE BEGIN 3 */
		#ifndef DEBUG_MODE
		LL_IWDG_ReloadCounter(IWDG);
		#endif
  }
  /* USER CODE END 3 */
}

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
/* USER CODE BEGIN 4 */

//обработка прерывания по нажатию кнопки "сброс"
void rst_callback(void)
{
	if (!LL_GPIO_IsInputPinSet(RST_GPIO_Port, RST_Pin))	//если состояние входа - 0, кнопка нажата
	{
		flags.rst_push = 1;	//поднимаем флаг нажатия 
	}
}

//обработка прерывания по нажатию кнопки "далее"
void nxt_callback(void)
{
	if (!LL_GPIO_IsInputPinSet(NEXT_GPIO_Port, NEXT_Pin))	//если состояние входа - 0, кнопка нажата
	{
		if (flags.nxt_push == 0)
		{
			flags.nxt_push = 1;	//поднимаем флаг нажатия
		}
	}
}

//обработка прерывания по нажатию кнопки "установка"
void set_callback(void)
{
	if (!LL_GPIO_IsInputPinSet(SET_GPIO_Port, SET_Pin))	//если состояние входа - 0, кнопка нажата
	{
		flags.set_push = 1;	//поднимаем флаг нажатия 
	}
}

//обработка прерывания по нажатию кнопки "время"
void time_callback(void)
{
	if (!LL_GPIO_IsInputPinSet(TIME_GPIO_Port, TIME_Pin))	//если состояние входа - 0, кнопка нажата
	{
		flags.time_push = 1;	//поднимаем флаг нажатия 
	}
}

//обработка прерывания таймера 1
void tim1_callback(void)
{
	if(LL_TIM_IsActiveFlag_UPDATE(TIM1))			//если флаг прерывания т/с
	{
		LL_TIM_ClearFlag_UPDATE(TIM1);					//опускаем флаг прерывания
		vars.seconds++;													//считаем секунду
	}
}

//обработка прерывания таймера 2
void tim2_callback(void)
{
	if(LL_TIM_IsActiveFlag_UPDATE(TIM2))			//если флаг прерывания таймера поднят
	{
		LL_TIM_ClearFlag_UPDATE(TIM2);					//опускаем флаг прерывания
		vars.millis++;													//считаем милисекунду
	}
}

/* USER CODE END 4 */
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


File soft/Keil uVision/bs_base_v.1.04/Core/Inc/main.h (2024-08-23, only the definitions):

#define NUM_OF_SLAVES 	20			//количество ведомых устройств
#define LED_Pin LL_GPIO_PIN_13
#define LED_GPIO_Port GPIOC
#define IRQ_Pin LL_GPIO_PIN_2
#define IRQ_GPIO_Port GPIOA
#define IRQ_EXTI_IRQn EXTI2_IRQn
#define CE_Pin LL_GPIO_PIN_3
#define CE_GPIO_Port GPIOA
#define CSN_Pin LL_GPIO_PIN_4
#define CSN_GPIO_Port GPIOA
#define TIME_Pin LL_GPIO_PIN_15
#define TIME_GPIO_Port GPIOA
#define TIME_EXTI_IRQn EXTI15_10_IRQn
#define NEXT_Pin LL_GPIO_PIN_3
#define NEXT_GPIO_Port GPIOB
#define NEXT_EXTI_IRQn EXTI3_IRQn
#define RST_Pin LL_GPIO_PIN_4
#define RST_GPIO_Port GPIOB
#define RST_EXTI_IRQn EXTI4_IRQn
#define SET_Pin LL_GPIO_PIN_5
#define SET_GPIO_Port GPIOB
#define SET_EXTI_IRQn EXTI9_5_IRQn
#define VERSION			1
#define SUBVERSION		04
#define DEV_INFO "kombo_bs base"
#define DWT_CONTROL *(volatile unsigned long *)0xE0001000
#define SCB_DEMCR   *(volatile unsigned long *)0xE000EDFC
#define ADRESS_LIST		{0x01, 0x02, 0x03, 0x04, 0x05, 0x06, 0x07, 0x08, 0x09, 0x0A, 0x0B, 0x0C, 0x0D, 0x0E, 0x0F, 0x10, 0x11, 0x12, 0x13, 0x14}
#define CHARS_LIST		{'0', '1', '2', '3', '4', '5', '6', '7', '8', '9', 'a', 'b', 'c', 'd', 'e', 'f', 'g', 'h', 'i', 'j'}
#define NUM_LIST		{0, 1, 2, 3, 4, 5, 6, 7, 8, 9, 10, 11, 12, 13, 14, 15, 16, 17, 18, 19}
#define ADRESS_LIST		{0x01, 0x02, 0x03, 0x04, 0x05, 0x06}
#define CHARS_LIST		{'0', '1', '2', '3', '4', '5'}
#define NUM_LIST		{0, 1, 2, 3, 4, 5}
#define RESET_CMD				0xFF		//команда аппаратного сброса
#define NOT_PUSHED 			0xFFFFFFFF	//сообщение "кнопка не нажата"
#define LED_STAT				0x01
#define LED_STAT_ON			0x01		//команда включения светодиода
#define LED_STAT_OFF		0x00		//команда отключения светодиода
#define LED_STAT_TGL		0x02
#define USART_COMMAND		0x31
#define USART_RESET			0x31
#define USART_NEXT			0x32
#define ERR_OK					0x00
#define NRF_ERR					0xFF
#define STRING_SIZE			64			//размер строк
#define SCAN_PERIOD 		1
#define SCAN_PERIOD 		2
#define BOUNCE_OFFSET		100

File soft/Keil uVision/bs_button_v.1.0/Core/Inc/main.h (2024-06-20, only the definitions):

#define LED_Pin LL_GPIO_PIN_1
#define LED_GPIO_Port GPIOA
#define IRQ_Pin LL_GPIO_PIN_2
#define IRQ_GPIO_Port GPIOA
#define IRQ_EXTI_IRQn EXTI2_3_IRQn
#define CE_Pin LL_GPIO_PIN_3
#define CE_GPIO_Port GPIOA
#define CSN_Pin LL_GPIO_PIN_4
#define CSN_GPIO_Port GPIOA
#define BUT_Pin LL_GPIO_PIN_1
#define BUT_GPIO_Port GPIOB
#define BUT_EXTI_IRQn EXTI0_1_IRQn
#define NVIC_PRIORITYGROUP_0         ((uint32_t)0x00000007) /*!< 0 bit  for pre-emption priority,
#define NVIC_PRIORITYGROUP_1         ((uint32_t)0x00000006) /*!< 1 bit  for pre-emption priority,
#define NVIC_PRIORITYGROUP_2         ((uint32_t)0x00000005) /*!< 2 bits for pre-emption priority,
#define NVIC_PRIORITYGROUP_3         ((uint32_t)0x00000004) /*!< 3 bits for pre-emption priority,
#define NVIC_PRIORITYGROUP_4         ((uint32_t)0x00000003) /*!< 4 bits for pre-emption priority,
#define VERSION			1
#define SUBVERSION	0
#define VREFINT_CAL ((uint16_t*) VREFINT_CAL_ADDR)
#define CALIBR_VREF 3.316//2.994f//4.257f
#define ERR_OK					0x00				//отсутствие ошибок
#define NRF_ERR					0xFF				//ошибка радиомодуля
#define OUR_ADDR				0x14				//адрес кнопки (должен быть в списке адресов базы)
#define RESET_CMD				0xFF				//команда аппаратного сброса
#define NOT_PUSHED 			0xFFFFFFFF	//сообщение "кнопка не нажата"
#define LED_STAT				0x01				//команда задания состояния светодиода
#define LED_STAT_ON			0x01				//команда включения светодиода
#define LED_STAT_OFF		0x00				//команда отключения светодиода
#define LED_STAT_TGL		0x02				//команда запуска моргания светодиода
#define LED_TGL_MS			100					//полупериод моргания светодиода

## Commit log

2024-08-23 first update
    Проект прошивки базы заменен на более актуальный.
    Добавлены новые варианты корпуса игровых кнопок
    [base_box_v.1.0.stl, base_box_v.1.0_verh.stl, box_button_v.1.2_niz.stl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]
2024-10-23 Корректировка схемы
